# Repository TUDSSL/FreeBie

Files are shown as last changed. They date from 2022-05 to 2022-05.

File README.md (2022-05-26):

# Battery-free Bluetooth That Works
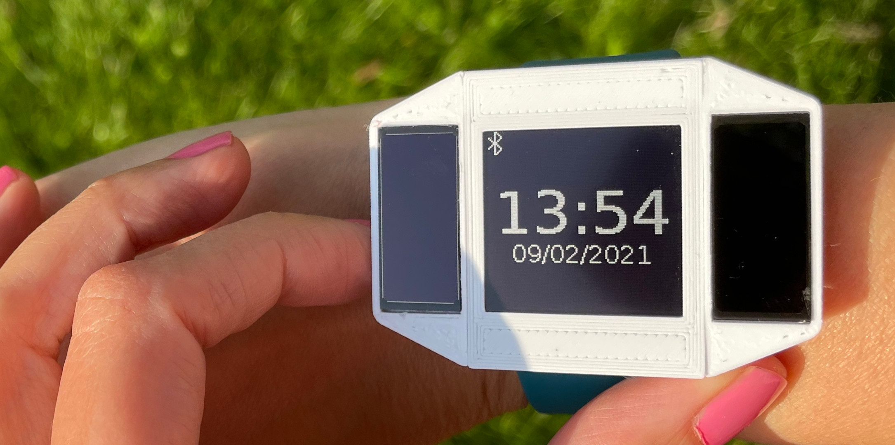
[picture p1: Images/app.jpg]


## Abstract
We present an architecture for intermittently-powered wireless communication systems that does not require any changes to the official protocol specification. Our core idea is to save the intermediate state of the wireless protocol to non-volatile memory within each connection interval. The protocol state is then deterministically restored at a predefined (harvested energy-dependent) time, which follows the connection interval. As a case study for our architecture, we introduce FreeBie: a battery-free intermittently-powered Bluetooth Low Energy (BLE) mote. To the best of our knowledge FreeBie is the first battery-free active wireless system that sustains bi-directional communication on intermittent harvested energy. The strength of our architecture is articulated by FreeBie consuming at least 9.5 times less power during device inactivity periods than a state-of-the-art BLE device.

<!-- ![Intermittency Introduction](https://github.com/TUDSSL/FreeBie/blob/master/Images/intro.svg) -->
<!-- ![System Diagram](https://github.com/TUDSSL/FreeBie/blob/master/Images/diagram.svg) -->

## Artifact
We describe the process to reproduce the results presented in the paper.

### Repository structure
The diagram below describes structure and purpose of the most important directories of the FreeBie project.
* * *
 * Hardware
   * design: KiCad design files
   * schematic: PDF schematic
   * manufacturing: Bill of materials, Gerber files (per version)
 * Software
   * bin: Location of compiled application binaries
   * build: Location of build files
   * ckpt-app: Application process files per application
     * fw-update
     * smartwatch
     * template
   * ckpt-os: OS process files
   * config: CMake and project configuration files
   * libs: Drivers for external system components
   * platforms: Pin definitions
   * third-party
     * Cordio: Network process files
 * Evaluation
   * hosts
     * fw-update: Firmware for the firmware update host
     * smartwatch: Android app for smartwatch host
     * end-device
       * softdevice: Power comparison application
   * Plotting
     * plot.sh: Script generating all the plots in the paper
     * *.py: Figure-specific Python script invoked by plot.sh
 * Measurements
     * raw: Raw measurements
     * converted: Measurements converted to CSV format
     * traces: 24H trace and replay script
* * *

### Evaluation Setup
#### Code Generation and Programming Tools.

To compile FreeBie runtime we used the [GNU Arm Embedded Toolchain (9.3.1)](https://developer.arm.com/tools-and-software/open-source-software/developer-tools/gnu-toolchain/gnu-rm/downloads) and [CMake (3.19.1)](https://cmake.org) to build the project. To program the MCU we used the [J-Link debug probe](https://www.segger.com/products/debug-probes/j-link/models/j-link-edu) with the accompanying J-Link software. We used Linux in order compile and evaluate FreeBie. In this artifact, only Linux instructions are provided, although (untested) Windows or Mac OS could also be used to build the system.

#### Trace Recording Tools.

We used [Saleae Logic Pro 16 logic analyzer](http://downloads.saleae.com/specs/Logic+Pro+16+Product+Fact+Sheet.pdf), to record on-device FreeBie signals. To capture and analyze over-the-air master/end-device BLE packets exchanges we used [Nordic Semiconductors nRF sniffer](https://www.nordicsemi.com/Products/Development-tools/nRF-Sniffer-for-Bluetooth-LE) and [Wireshark](https://www.wireshark.org}) as protocol analyzer.

#### Controlled Test Environment.

We put FreeBie at the bottom of a closed light box. A wirelessly-controlled [LED bulb](https://www.philips-hue.com/en-gb/p/hue-white-ambiance-1-pack-e27/8718699673147) was installed at the top of the box to create repeatable and controlled light source. A [luminosity meter](https://www.uni-trend.com/html/product/Environmental/Environmental_Tester/Mini/UT383.html) was placed next to FreeBie mote to measure the exact luminosity projecting onto FreeBie's solar panels.

#### Power Measurement Process.

Connection event as well as the sleep power consumption for the [Packetcraft BLE network stack](https://github.com/packetcraft-inc/stacks), Nordic Semiconductors BLE SoftDevice and our intermittently-powered BLE stack were measured using a [STMicroelectronics X-NUCLEO-LPM01A power measurement board](https://www.st.com/en/evaluation-tools/x-nucleo-lpm01a.html). FreeBie's power consumption whilst the processor domain is off was measured with [Keithley 2450 SMU](https://download.tek.com/datasheet/1KW-60904-2_2450_Datasheet_072021.pdf). Power consumption during sleep and power off was measured at 1.8V. Power consumption of Packetcraft and SoftDevice is measured on the NRF52840 development kit, FreeBie power measurements are measured on the FreeBie mote. The BLE connection event power consumption for Packetcraft and SoftDevice was measured at a 1.8V, while BLE connection event for FreeBie was measured at 2.67V. We measure the connection event after the device has been running for five minutes, selecting a connection event with an empty PDU. The consumed energy results presented in Figure 12 Consumed Energy are computed as the sum of the energy consumed during the selected connection event and during the idle period (power off for FreeBie and sleep for Packetcraft and SoftDevice.).

#### FreeBie Hardware.

In order to reproduce the results of the paper a FreeBie mote is required. In the *Hardware* folder of the repository, all files to reproduce the mote are provided, such as the design files, Gerber files and the bill of materials.

### Building the FreeBie Software

In order to build the FreeBie software, from the *Software/build* directory the following commands need to be executed.

```bash
$ cmake ..
$ make install
```

As a result of these operations, the project is compiled and the resulting programmable binaries of the applications are moved to the *Software/bin* directory. Next, the compiled binary of the application that is being tested should be flashed to the FreeBie mote.

#### Programming the FreeBie Mote.

In order to assist with programming the FreeBie mote during intermittent operation, a button is placed next to the programming header on the mote. When this button is pressed during startup of the MCU, the MCU remains in a perpetual loop, allowing the device to be programmed. Note that this button only works during the start up of the MCU and during operation the mote might be unable to be flashed as the power to the MCU may be switched off.

## Results Reproduction

### Smartwatch Application

In order to reproduce the results related to the smartwatch application please make sure that the smartwatch binary is programmed to the FreeBie mote first.

#### Building the Android Application.

In order to build the Android application, open the project (located in *evaluation/hosts/smartwatch*) in the Android Studio and then proceed with building the APK. Then a *.apk* file should be available in the *evaluation/hosts/smartwatch/build/outputs/apk* directory of the project. The APK must then be installed on the phone through Android Studio or transferred to the phone and installed manually. When opening the app for the first time, it will ask for permissions that must be granted in order for the app to be able to function. For more information please refer to the [Android Developer website]().

#### Measurement.

First the logic analyzer is connected to the testpoints on the FreeBie mote. These testpoints provide the tracing information about the system state used to generate Figure 11 FreeBie smartwatch operation. For the measurement, the programmed FreeBie mote with the smartwatch binary is placed in the light box. The phone should be placed within range of the FreeBie mote for the devices to be able to connect. Next the variable light should be set to output the amount of light specified in the desired scenario to be replicated.

When the light is switched on the FreeBie mote starts harvesting energy and when enough energy is harvested the FreeBie mote should automatically switch on. The smartphone should then automatically connect to the FreeBie mote and time should appear on the LCD screen.

#### 24 hour experiment.

For the 24 hour experiment the same procedure as before is used, but instead of a static lighting, a script (available in the *Measurements/traces* directory) is used to replay a prerecorded luminosity trace of a person wearing a smartwatch for 24 hours. In order to execute the Python script, first the dependencies have to be installed, assuming Python is already installed. For this the following command needs to be executed.

```bash
$ cd Measurements/traces
$ pip install -r requirements.txt
```

Second the tool communicating with the light has to be installed and configured. Please follow the instructions on the website of the [tool](https://github.com/bahamas10/hue-cli). After the software is able to control the light, the script can be executed, replaying 24H of the prerecorded light trace.

```bash
$ python replay_lux.py -f \
  logger-2021-11-20_09-36-46-549.csv -skips 5
```

### Firmware Update Application

We first note that in order to reproduce the results presented in the smartwatch application please make sure the *fw-update* binary is programmed to the FreeBie mote.

#### Building and Flashing the Host Firmware.

First plug in the development kit and make sure that is is powered and detected. Then from the main project directory execute the following command.

```bash
$ cd Evaluation/hosts/          \
     fw-update/  \
     nRF5_SDK_17.0.2/           \
     examples/ble_central/      \
     ble_app_custom_c/          \
     pca10056/s140/armgcc
$ make
$ make flash_softdevice
$ make flash
```

The development kit should now be flashed with the correct firmware. Turn the development kit off and on. Now it is ready to start the firmware update as soon as the FreeBie mote is detected.

#### Measurement.

In order to generate the Evaluation of firmware update plot in FreeBie Evaluation section, the logic analyzer is connected to the test points on the FreeBie mote. These test points provide the tracing information about the system state used to generate Figure 13 Evaluation of firmware update. For the measurement, the programmed FreeBie mote with the *fw-update* binary is placed in the light box. The development kit, acting as firmware update host, should be placed within range of the FreeBie mote for the devices to be able to connect. For the firmware update application we did not connect the display to the FreeBie mote.

When the light is switched on the FreeBie mote starts harvesting energy and when enough energy is harvested the FreeBie mote should automatically switch on. The firmware update host should connect to the FreeBie mote and the firmware update should start automatically.

### Reference Comparison

In order to produce figures 8, 9 and 12 we used a minimal working example (named *template*) of our software that only actively uses the network process and the OS process. In this application after the BLE connection is established and the database discovery has been completed, only empty packets are sent. Hence, this forms a point of reference for other experiments.

#### Template Configuration.

From within the *CMakefile* file of *template*, checkpointing can be switched off by commenting the following lines:
```CMake
set(CHECKPOINTING 1)
set(CHECKPOINTING_TIMING 1)
```
Without checkpointing enabled this example serves as the Packetcraft comparison point and is representative of traditional operation; with checkpointing enabled---as FreeBie. When the checkpointing is active, a connection update request to the selected parameters is sent after connecting. To force the same behavior for the non-checkpointing version, the line *set(COMPARE_NO_CHECKPOINT 1)* needs to be uncommented. When modifying the CMakefiles, the code has to be recompiled with the same steps as described in Section Building the FreeBie Software.

#### Intermittent versus Non-intermittent.

In order to reproduce the results in Figure 8 the FreeBie mote is again placed in a light box at the specified light level and the information about the system state are recorded by the logic analyzer. The experiment is ran for both checkpointing enabled and checkpointing disabled. The non-checkpointed version runs out of energy and not be able to recover the connection as the system state is lost.

#### Connection Recovery.

For the results in Figure 9, the FreeBie mote is not powered by the solar panels but through an external power supply connected to the test point *VSol* on the back of the FreeBie mote. In this case *template* with connection recovery enabled (*set(RECOVER_CONNECTIONS 1)*) and checkpointing enabled is used. After a connection to the FreeBie mote has been established, the power to the device is disabled until the device suffers from a power failure. Then power is resumed and the device attempts recovery.

#### Power Measurement.

For the results in Figure 12 *template* is used with checkpointing disabled, serving as the Packetcraft comparison point; with checkpointing enabled---as FreeBie. As the comparison point of SoftDevice the code provided in *Evaluation/end-device/softdevice* is used. From the main project directory the code can be compiled and flashed using the following commands.

```bash
$ cd Evaluation/end-device/softdevice/ \
     examples/ble_peripheral/ \
     ble_app_pwr_profiling/ \
     pca10056/s140/armgcc
$ make
$ make flash_softdevice
$ make flash
```

Please refer to the Evaluation Setup Section for more information about the power measurement process.

### Plotting

By executing the *plot.sh* script in the *Plotting* directory all of the plots can be generated. Please note that due to the size of the 24 hour plot this might take more than 15 minutes and requires a system with at least 16GB of RAM. All plotting scripts use Python and assume Python is installed on the system; all Python dependencies can be installed via the *requirements.txt* file using the following commands.

Since the measurements files are large they are only included in the version of the artifact hosted on [Zenodo](https://doi.org/10.5281/zenodo.6583725)

```bash
$ cd Plotting
$ pip install -r requirements.txt
$ plot.sh
```

## License
The Project adopts the MIT license unless noted otherwise, As Packetcraft licenses its software stack under the Apache 2.0 license our code in the folder Software also adopts this license unless noted otherwise.

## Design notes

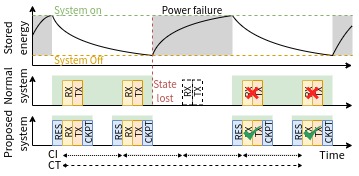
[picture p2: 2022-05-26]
Images/intro.jpg

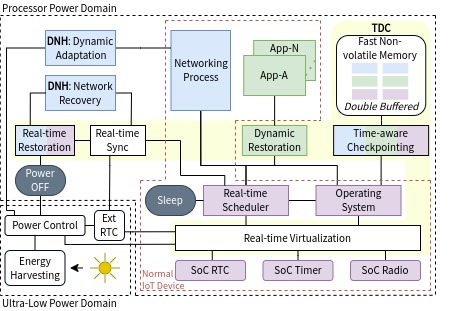
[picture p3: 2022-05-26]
Images/diagram.jpg

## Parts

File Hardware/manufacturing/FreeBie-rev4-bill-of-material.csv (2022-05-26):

Item | Qty | Reference(s) | MPN
1 | 11 | C1, C3, C4, C7, C8, C9, C10, C21, C22, C23, C25 | GRM155R71C104KA88J
2 | 2 | C5, C6 | 0402ZD105KAT2A
3 | 1 | C11 | GJM1555C1H470FB01D
4 | 2 | C12, C16 | LMK105BBJ475MVLF
5 | 2 | C13, C15 | GCM155R71H103KA55D
6 | 2 | C14, C17 | -
7 | 2 | C18, C19 | CPX3225A
8 | 1 | C20 | GRM188R60J226MEA0D
9 | 1 | J1 | 52745-1097
10 | 1 | J2 | -
11 | 2 | J3, J4 | 202396-0207
12 | 6 | JP1, JP2, JP9, JP11, JP12, JP14 | -
13 | 1 | JP3 | -
14 | 1 | L1 | VLS252012CX-220M-1
15 | 1 | L2 | VLS252012CX-100M-1
16 | 10 | R1, R3, R5, R6, R7, R8, R9, R15, R21, R22 | RC0402FR-0710ML
17 | 2 | R2, R10 | RC0402FR-07100KL
18 | 1 | R4 | RC0402FR-0710ML
19 | 1 | R12 | MCHVR02FTFY3904
20 | 2 | R13, R16 | CRCW04029M10FKED
21 | 1 | R14 | CRCW04025M23FKED
22 | 1 | R17 | CRCW04023M16FKED
23 | 1 | R18 | RMCF0402FT4M53
24 | 1 | R19 | MCHVR02FTFY6804
25 | 1 | R20 | RC0402FR-07200KL
26 | 1 | SW2 | B3U-1000P
27 | 13 | TP1, TP2, TP3, TP4, TP5, TP6, TP7, TP9, TP11, TP12, TP13, TP14, TP18 | SMOX/060/B1/HT
28 | 1 | U1 | BQ25570RGR
29 | 1 | U2 | 74AUP1G74
30 | 1 | U3 | 74AUP1G97DCK
31 | 1 | U4 | OPT3004DNPR
32 | 1 | U5 | BMA400
33 | 1 | U6 | TS3A4741DCN
34 | 1 | U7 | EYSKBNZWB
35 | 1 | U8 | MB85RS4MT
36 | 1 | U9 | SN74AUP3G34RSE
37 | 1 | U10 | AM1815
38 | 1 | U11 | SN74AUP1G04DCK
39 | 1 | U12 | SN74AUP1G34DCK
40 | 1 | Y1 | ABS07W-32.768KHZ-J-1-T
Misc:
 | 2 | Solar panel | EX2-1V50
 | 1 | Screen | LS013B7DH03
 | 10 | Solar panel connector contact | 5013340000
 | 2 | Solar panel connector connector | 5013300200

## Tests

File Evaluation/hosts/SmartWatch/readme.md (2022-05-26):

Bluetooth handling is based on:https://github.com/weliem/blessed-android

Also inspired by https://github.com/androidthings/sample-bluetooth-le-gattserver

With mail handling from https://stackoverflow.com/a/28689722

Time profile taken from https://github.com/androidthings/sample-bluetooth-le-gattserver

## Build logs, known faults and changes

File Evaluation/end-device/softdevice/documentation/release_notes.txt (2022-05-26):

nRF5 SDK v17.0.0
------------------------
Release Date: June, 2020

Highlights:

- Added support for a new chip: nRF52820
- Added support for a new SoftDevice: S122 
 (size-optimized central-only Bluetooth Low Energy SoftDevice)
- Added a driver for the new RF front-end module nRF21540
- Removed IoT components and examples
- Removed Keil 4 support

The following toolchains/devices have been used for testing and verification:

 - ARM: MDK-ARM version 5.25
 - GCC: GCC ARM Embedded 9.2019q4.major
 - IAR: IAR Workbench 7.80.4
 - SES: SES 4.50

*****
Note for IAR 8 users:
(Libraries for IAR 8 require wchar_t to be of size 32 bits while IAR 7 requires 16 bits).

To run a project using IAR 8, follow these intructions:
 - Open the IAR project in IAR 8. The IAR workbench will automatically generate an IAR 8 compatible project file.
 - If the project contains one of the precompiled libraries listed below, replace it
   with the IAR 8 compatible alternative (there are no projects targeting nRF51 in this SDK).
 - Save the project.
 - When building the project, you might get the warning: "The header file 'cmsis_iar.h' is obsolete and should not be used. [...]".
    - The problem is described in DevZone post: https://devzone.nordicsemi.com/f/nordic-q-a/31123/iar-ewarm-8-22-1-complains-about-cmsis_iar-h
      The solution is to remove all occurrences of #include <cmsis_iar.h>.

The affected libraries are:
 - micro-ecc crypto:
    - IAR7: Includes library located in the folder named “…_iar\…”.
    - IAR8: Switch to using the library from the folder named “…_armgcc\…”.
 - nrf_cc310, nrf_cc310_bl, and nrf_oberon:
    - IAR7: Link to a library where “short_wchar” is part of the folder name.
    - IAR8: Link to a library without “short_wchar” in part of the folder name.
 - Gazell, NFC Tag, and 802.15.4:
    - IAR7: Includes the library where the file name ends with “_iar”.
    - IAR8: Switch to using the library with similar file name that ends with “_gcc”.
*****

Supported SoftDevices:
 - S112 v7.x.x
 - S113 v7.x.x
 - S122 v8.x.x
 - S132 v7.x.x
 - S140 v7.x.x
 - S212 v6.1.x
 - S312 v6.1.x
 - S332 v6.1.x
 - S340 v6.1.x

Supported boards:

- PCA10040
- PCA10040E (nRF52810 emulation on PCA10040)
- PCA10056
- PCA10056E (nRF52811 emulation on PCA10056)
- PCA10100 (support in selected examples)
- PCA10100E (nRF52820 emulation on PCA10100)
- PCA10059 (support in selected examples)
- D52DK1 from Garmin Canada (only for ANT examples)
- PCA10112 (nRF52840 with the nRF2140 front-end chip)

For other devices and boards, see the SDK documentation, section "Using
the SDK with other boards".

*** New features
*****************

** Drivers and libraries **

- nRF21540 Front-End Module support:
    - New driver supporting the nRF21540 RF front-end module
      can be found in '.\driver_ext\nrf21540\'
    - The DTM and Radio Test examples have been updated
      to include the nRF21540 driver (only GPIO control has been tested).
    - Workaround handling Errata 1 for nRF21540 is not included as part of
      the driver and must be applied separately.
- Radio Test example:
    - Extended the 'start_tx_modulated_carrier' command with an additional
      option for setting the specific number of packets to transmit.
    - Added printing of the received packet statistics in the 'print_rx' command handler.
- nrfx:
    - Updated version to 1.8.4.
    - Added support of the nRF52820 device.
    - Added new SAADC driver backported from nrfx 2.2.0 branch.
- nrf_cc310:
    - Updated version to 0.9.13.
    - Bugfix release with new mechanism for enabling and disabling the hardware
      and for interrupt masking. See Migration Guide for details.
- nrf_cc310_bl
    - Updated version to 0.9.13.
    - Bugfix release with new mechanism for interrupt masking.
- nrf_oberon
    - Updated version to 3.0.5.
    - General version update supporting more nRF5 architectures.
    - Addition of header files for the mbedcrypto frontend.
	  See Migration Guide for details.
- USB: added support for nRF52820.

*** Changes
***********

** Drivers and libraries **

- Radio Test example: refactored to use the Radio HAL module (nrf_radio.h) functions.
- nrfx: see the nrfx 1.8.4 changelog in modules/nrfx/CHANGELOG.md.

** Crypto **

- nrf_cc310 library now automates enabling and disabling of CryptoCell hardware
  and interrupts. It is no longer done in nrf_crypto. See Migration Guide for details.

** NFC **

- T4T: allowed dynamic R/W NDEF message buffer changing.
  Now you can change the NDEF buffer in any protocol state,
  without having to disable the T4T emulation.
- T4T: added pointer to the NDEF message buffer for the 'NDEF Updated' event.

** Bluetooth Low Energy **

- Scanning Module: removed the 'Scan Request' event
  that is irrelevant for the scanner role.
- External Tile library: integrated a new library version.

** DTM **

 - Updated DTM to support the nRF52820 device.
 - Added new example targets:
   - pca10100e: for nRF52820 emulation on pca10100.
   - pca10112: a version for a development kit with the nRF52840 device
     and the nRF2140 front-end chip.

*** Bug fixes
****************

** Drivers and libraries **

- nrfx: see the nrfx 1.8.4 changelog in modules/nrfx/CHANGELOG.md.
- Fixed a bug where FDS garbage collection ran on more pages than necessary,
  causing unnecessary flash wear.

** ANT **

- ANT Shared Channels example (slave project): fixed array size check.

** NFC **

- T4T: fixed detecting of the end of reading NDEF message procedure
 (NFC_T4T_EVENT_NDEF_READ).
- T4T: fixed an issue where NDEF Read event was triggered even when
  NDEF Message was empty.

** Bluetooth Low Energy **

- Fixed nrf_sd_def.h file contents in all SoftDevices
  (in some cases, the definitions in this file were outdated).
- External Tile library: fixed a few minor issues.
- Nordic UART Service: added a null-pointer check in the
  notification transmitted handler.
- Fixed a vulnerability issue reported by IOActive where malformed
  advertising data could be used to attack a device that does scanning.
  The fix is included in ble_advdata_search() in ble_advdata.c where
  an extra check has been added to ensure that the length values specified
  within the advertising packet are within the boundary of the advertising packet.

** DFU **

- SES will now return a linker error if the bootloader is too large.
- Fixed a bug that caused SD+BL updates to fail if the SD had signature boot validation.
- Fixed an error in the code that booted the app, which could happen
  with certain optimization settings.
- Fixed a false positive assert that could sometimes happen after a reset
  during an upgrade.
- Fixed a bug that caused compilation errors when building with a board with no buttons.

** DTM **

- DTM reports regarding Max Octets are now correct for devices without long range support.

** USB **

- Fixed issues and optimized app_usbd_string_desc.
- Fixed issues in USB CLI backend when handling a port close.

** Proprietary **

- Gazell: fixed an assertion that would be sometimes generated after
  a packet transmission.
- ESB: fixed a bug in the nrf_esb_pop_tx function where packages would get sent anyway
  in certain situations.

*** Known Issues
****************

** General **

- The workaround for Anomaly 198 for nRF52840 SPIM3 peripheral
  that has been implemented in nrfx_spim cannot be used with a SoftDevice.
  Flag NRFX_SPIM3_NRF52840_ANOMALY_198_WORKAROUND_ENABLED must be set to zero.
  The workaround based on a dedicated RAM block for SPIM3 must be used instead.
- usbd_msc example has a limitation.
  With setting "APP_USBD_CONFIG_EVENT_QUEUE_ENABLE = 0",
  when USB cable is unplugged and re-plugged, the application goes into an endless loop.
  This is due to an issue in the unsupported block device library.

** Bluetooth Low Energy **

- GATTC: the ble_gattc_service_t::uuid field is incorrectly populated
  in the BLE_GATTC_EVT_PRIM_SRVC_DISC_RSP event if the
  sd_ble_gattc_primary_services_discover() or sd_ble_gattc_read()
  are called when a Primary Service Discovery by Service UUID is already ongoing.
  When the application has called sd_ble_gattc_primary_services_discover(),
  it should wait for the BLE_GATTC_EVT_PRIM_SRVC_DISC_RSP event before calling
  sd_ble_gattc_primary_services_discover() or sd_ble_gattc_read().
- BLE Interactive CLI example: the command to set a custom ATT MTU only takes
  effect on the subsequent connection and the updated MTU parameter is not
  maintained in further connections with the same peer, even when bonded.
- ANT Shared Channels example: when testing a Bluetooth Low Energy connection
  with an Android device, the link is terminated by Android due to unhandled LL requests.
- Bluetooth ANCS example: when connected from iPhone and pressing DK buttons,
  the example may assert before the Bluetooth Low Energy link is authenticated.

** Crypto **

- The nrf_crypto CLI example may fail when using an ECC private key converted
  from raw function for specific curve types.

** Drivers and libraries **

- The SAADC driver (from nrfx 1.8.x) does not handle detection limits 'high' and 'low'
  correctly if SAADC resolution is greater than 10 bits.
  SAADC driver ported from nrfx 2.2.x is not affected by this.
- USBD:
  - The library may handle Remote Wakeup incorrectly.
  - Issuing a SET_ADDRESS(0) request does not cause the device to change
    its state to default.
  - The device does not STALL when a DATA transaction is received outside of SETUP.
    It ACKs instead.
- The following macros defined in boards.h work only with pins on port 0:
  - LEDS_OFF
  - LEDS_ON
  - LED_IS_ON
  - LEDS_INVERT
  - LEDS_CONFIGURE
- The low_power_pwm library does not correctly initialize GPIOs
  that are placed on PORT1 in the low_power_pwm_init function.
  This indirectly affects the led_softblink library and can also affect
  the DFU open bootloader.

==============================

nRF5 SDK v16.0.0
------------------------
Release Date: October, 2019

Highlights:

- Added support for a new chip: nRF52833
- Added support for new BLE SoftDevices version 7, as well as the new SoftDevice S113.
- Added an external Tile BLE library and a corresponding example
  demonstrating the "find me" feature.
- App Timer v2 is now out of experimental and replaces the legacy App Timer
  in all examples.

The following toolchains/devices have been used for testing and verification:

 - ARM: MDK-ARM version 5.25
 - GCC: GCC ARM Embedded 7.2018q2.update
 - IAR: IAR Workbench 7.80.4
 - SES: SES 4.18

*****
Note for IAR 8 users:
(Libraries for IAR 8 require wchar_t to be of size 32 bits while IAR 7 requires 16 bits).

To run a project using IAR 8, follow these intructions:
 - Open the IAR project in IAR 8. The IAR workbench will automatically generate an IAR 8 compatible project file.
 - If the project contains one of the precompiled libraries listed below, replace it
   with the IAR 8 compatible alternative (there are no projects targeting nRF51 in this SDK).
 - Save the project.
 - When building the project, you might get the warning: "The header file 'cmsis_iar.h' is obsolete and should not be used. [...]".
    - The problem is described in DevZone post: https://devzone.nordicsemi.com/f/nordic-q-a/31123/iar-ewarm-8-22-1-complains-about-cmsis_iar-h
      The solution is to remove all occurrences of #include <cmsis_iar.h>.

The affected libraries are:
 - micro-ecc crypto:
    - IAR7: Includes library located in the folder named “…_iar\…”.
    - IAR8: Switch to using the library from the folder named “…_armgcc\…”.
 - nrf_cc310, nrf_cc310_bl, and nrf_oberon:
    - IAR7: Link to a library where “short_wchar” is part of the folder name.
    - IAR8: Link to a library without “short_wchar” in part of the folder name.
 - Gazell, NFC Tag, and 802.15.4:
    - IAR7: Includes the library where the file name ends with “_iar”.
    - IAR8: Switch to using the library with similar file name that ends with “_gcc”.
*****

Supported SoftDevices:
 - S112 v7.x.x
 - S113 v7.x.x
 - S132 v7.x.x
 - S140 v7.x.x
 - S212 v6.1.x
 - S312 v6.1.x
 - S332 v6.1.x
 - S340 v6.1.x

Supported boards:

- PCA10040
- PCA10040E (nRF52810 emulation on PCA10040)
- PCA10056
- PCA10056E (nRF52811 emulation on PCA10056)
- PCA10100 (support in selected examples)
- PCA10059 (support in selected examples)
- D52DK1 from Garmin Canada (only for ANT examples)

For other devices and boards, see the SDK documentation, section "Using
the SDK with other boards".

*** New features
*****************

** Drivers and libraries **

- nRF52833: added USB support - both USB device hardware driver and USB Device library.
- Radio Test Example: added a project for nRF52833.

** BLE**

- Added a new library GATT Queue which can be used for buffering GATT procedures when
  the SoftDevice cannot process them immediately. It can be used with, for example,
  Indications, Read or Write Requests etc. The queued procedure is automatically
  retried when events from the SoftDevice indicate that it can be processed.
  Most of the GATT Client libraries use this module.
- Added support for the new SoftDevice S113 in selected BLE examples.
- Improved Database Discovery Module design to enable multiple instances,
  for example to perform independent discovery on each connection.
- BLE Interactive CLI Example: added discovery of 128-bit UUID Services and
  Characteristics at the first attempt.
- Advertising Module: improved dynamic advertising data update, no additional buffer
  is needed now - swap buffer was introduced within the module implementation.
- Added a new external BLE library: Tile, and a corresponding example: ble_app_tile.
  The project implements proprietary GATT services for demonstrating the
  "find me" feature.
  The integrated modules include source code as well as a precompiled linkable library.

** DFU **

- Updated documentation with information on Secure Boot and platform architecture
  security.

** NFC **

- Added support for new chip: nRF52833. Added corresponding projects in selected
  examples.

** USB **

- APP_USBD_BCD_VER_MAKE macro now includes a sub-minor version parameter.
- Feature reports functionality is now supported in HID generic class.

** Proprietary **

- ESB: added support for the new chip nRF52833.
- Gazell: added support for nRF52810 and nRF52811.

** DTM **

- Updated Direct Test Mode to support nRF52833.

*** Changes
***********

** Drivers and libraries **

- app_timer: App Timer v2 moved out of experimental. It is updated and
  API-compatible with the old implementation making it easy to replace.
  All SDK examples using App Timer are updated to use the new version.
- libuarte:
   - libuarte moved out of experimental.
   - nrf_libuarte renamed to nrf_libuarte_drv (file names and API).
   - Added option to use an app_timer instance for RX timeout instead of the TIMER or
     RTC peripheral.
- nrf_cli: CLI now automatically adds an `\r` character before each printed `\n`
  character. This feature can be switched off in sdk_config with flag
  `NRF_FPRINTF_FLAG_AUTOMATIC_CR_ON_LF`.
- FDS: FDS-specific error codes have been moved so their values do not overlap with
  other error codes.
  Also, NRF_SUCCESS is now used instead of FDS_SUCCESS.

** Crypto **

- Updated OPTIGA Trust X library code and example.
- Updated the nrf_oberon library version to 3.0.1, changing the API prefixes from
  occ_* to ocrypto_*.

** BLE **

- Peer Manager:
    - Changed the pm_peer_data_* API to use uint32_t length variables instead of
      uint16_t.
    - The flash cleaning algorithm in peer_manager_handler now also runs garbage
      collection if other users of FDS have deleted data.
    - The fds_error member variable has been removed from PM events.
    - Added a LESC flag to pm_conn_sec_status_t.
    - Add a new function pm_sec_is_sufficient() where the security state of the
	  connection is checked against a reference security state.
    - Function pm_sec_is_sufficient() is now used internally when responding
   	  to slave security requests.
    - pm_handler has been augmented with new event handlers based on
      pm_sec_is_sufficient().
- Advertising Module: removed obsolete API.
- ble_conn_state: Added a LESC flag to connection state (i.e. whether LESC was used
  for bonding/pairing). It can be false even if LESC was used.
  See Peer Manager for a completely accurate reporting of LESC.
- BLE Central UART Example: added support for Windows-type line end characters.
- Running Speed and Cadence Example: added handling of the Database Discovery Available
  event.
- Heart Rate Example:
    - Changed default configuration for nRF52810 and nRF52811.
         - Service Change Characteristic disabled.
         - Disabled protection against repeated pairing attempts in Peer Manager.
         - FDS: Reduced number of virtual flash pages to use.

** DFU **

- Bootloader start address is now placed in UICR at compile time, and the MBR page is
  populated at runtime. This is to mitigate problems with flashing
  where the MBR was erased.
- The MBR folders have been merged into a single folder since the MBR is identical for
  all nRF52 variants.
- The bootloader now disallows upgrading the SoftDevice to another family
  (e.g. s140 -> s113).
- nrf_bootloader_app_start() can no longer be called from an interrupt handler.
- BLE DFU: Disconnect link when aborting DFU (OP_ABORT).
- The bootloader will now wait a configurable number of milliseconds before each chip
  reset. Configured with NRF_BL_RESET_DELAY_MS.
- Added a configuration option for disabling a debug port: NRF_BL_DEBUG_PORT_DISABLE.
- When the bootloader is compiled in a configuration where the app does not need access
  to the settings page, the page itself, not just the backup, is locked before booting
  the app.

** USB **

- USB driver: all changes listed here:
  https://github.com/NordicSemiconductor/nrfx/blob/v1.8.0/CHANGELOG.md
- USB libraries: APP_USBD_AUDIO_AC_IFACE_SUBTYPE_OUTPUT_TERNINAL
  has been renamed to APP_USBD_AUDIO_AC_IFACE_SUBTYPE_OUTPUT_TERMINAL.
- bDescriptorSubType field in app_usbd_audio_ac_iface_header_desc_t struct
  has been renamed to bDescriptorSubtype.
- bmRequest field in app_usbd_cdc_notify_t struct has been renamed to bRequest.
- bmRequest field in app_usbd_setup_t struct has been renamed to bRequest.
- New values have been added to app_usbd_msc_subclass_t and app_usbd_msc_req_t enums.
- Terminal link in AS Interface Descriptor has been added as a parameter
  for the APP_USBD_AUDIO_GLOBAL_DEF macro.

*** Bug fixes
****************

** Drivers and libraries **

- FDS: fixed two bugs where a power loss at very specific times during garbage
  collection could corrupt the file system, making FDS unable to initialize and return
  FDS_ERR_NO_PAGES on initialization.
- FDS: fixed a bug that prevented using the last word of a flash page to save a record.

** ANT **

- Fixed a bug in ANT-FS Library, where incoming burst frames could be incorrectly
  handled due to wrong bitfield checking.

** NFC **

- Fixed a bug where the Tag could respond to an ALL_REQ frame with incorrect timing when
  in the sleep state.
  This bug would occur after the Tag received an SLP_REQ frame and when an ALL_REQ frame
  was received shortly after - in a time shorter than what was configured
  in the NFCT FRAMEDELAYMAX register (in Type 4 Tag default configuration: 4.8 ms).

** BLE **

- Eddystone: fixed bug for handling 0.625 unit in advertising interval.
- Advertising Module: fixed a bug where a secondary PHY configuration might get
  overwritten.
- Advertising Data Encoder: fixed a bug causing underflow of a return value
  of the parsing function when malformed data was provided as input.
- Nordic UART Service: fixed a bug where incorrect Characteristic CCCD
  was checked on connection event.
- Database Discovery: fixed counting of discovered services.
   - Fixed a bug where "available" events (indicating the module is ready
     for the next discovery process) were not triggered.
- BLE Interactive CLI Example: fixed a bug where not all
  GATT Characteristics and Descriptors were discovered when a short ATT MTU was used.
- Peer Manager:
    - Fixed a bug where peer ranks would not work after deleting all peers.
    - Fixed a bug where the indications for service changed would be dropped
      if they were sent at the same time as an MTU exchange.

** DFU **

- Fixed a bug where resuming a DFU procedure with a disconnect (but no reset)
  in-between could leave the bootloader in a semi-locked state.
- Fixed an issue where write protection of the application was not applied.

*** Known Issues
****************

** General **

- The workaround for Anomaly 198 for nRF52840 SPIM3 peripheral
  that has been implemented in nrfx_spim cannot be used with a SoftDevice.
  Flag NRFX_SPIM3_NRF52840_ANOMALY_198_WORKAROUND_ENABLED must be set to zero.
  The workaround based on a dedicated RAM block for SPIM3 must be used instead.

** BLE **

- GATTC: the ble_gattc_service_t::uuid field is incorrectly populated
  in the BLE_GATTC_EVT_PRIM_SRVC_DISC_RSP event if the
  sd_ble_gattc_primary_services_discover() or sd_ble_gattc_read()
  are called when a Primary Service Discovery by Service UUID is already ongoing.
  When the application has called sd_ble_gattc_primary_services_discover(),
  it should wait for the BLE_GATTC_EVT_PRIM_SRVC_DISC_RSP event before calling
  sd_ble_gattc_primary_services_discover() or sd_ble_gattc_read().
- The TFTP Background DFU example has known instabilities.
- The Tile example disconnects when notifications in the Tile service are on
  and the application sends the first Battery Level notification.
- BLE Interactive CLI example: the command to set a custom ATT MTU only takes
  effect on the subsequent connection and the updated MTU parameter is not
  maintained in further connections with the same peer, even when bonded.
- ANT Shared Channels example: when testing BLE connection with an Android device,
  the link is terminated by Android due to unhandled LL requests.
- Bluetooth ANCS example: when connected from iPhone and pressing DK buttons,
  the example may assert before the BLE link is authenticated.

** Crypto **

- The nrf_crypto CLI example may fail when using ecc private key converted
  from raw function for specific curve types.

** Drivers and libraries **

- The SAADC driver does not handle detection limits 'high' and 'low' correctly
  if SAADC resolution is greater than 10 bits.
- USBD:
  - The library may handle Remote Wakeup incorrectly.
  - Issuing a SET_ADDRESS(0) request does not cause the device to change
    its state to default.
  - The device does not STALL when a DATA transaction is received outside of SETUP.
    It ACKs instead.

** IoT **

- The MQTT example does not compile when run on PCA10040 with commissioning
  enabled (COMMISSIONING_ENABLED=1).
- DTLS example: the server and the client application of the DTLS example should
  not be run on two kits. Instead, either the server or the client application
  should be run against the PC application as described in the documentation.

===========================================

nRF5 SDK v15.3.0
------------------------
Release Date: Week 7, 2019

Highlights:

- Added support for a new chip - nRF52811.
- Added support for two new ANT SoftDevices: S312 targeting nRF52810 and nRF52832, and S340 targeting nRF52840.
- Added back support for the ANT SoftDevice S332 v6.1.1, as well as updated the latest SoftDevices S112, S132, S140 and S212 v6.1.1.
- Updated the SDFU solution with ANT transport layer.
- Updated DTM to support nRF52811, and updated the existing code to correctly handle Anomaly 172.

The following toolchains/devices have been used for testing and verification:

 - ARM: MDK-ARM version 5.25
 - GCC: GCC ARM Embedded 7.2018q2.update
 - IAR: IAR Workbench 7.80.4
 - SES: SES 4.12

Note: The selected GCC version has shown instabilities when using the Link Time Optimization feature, and using the feature is not recommended.

*****
Note for IAR 8 users:
(Libraries for IAR 8 require wchar_t to be of size 32 bits while IAR 7 requires 16 bits).

To run a project using IAR 8, follow these intructions:
 - Open the IAR project in IAR 8. The IAR workbench will automatically generate an IAR 8 compatible project file.
 - If the project contains one of the precompiled libraries listed below, replace it with the IAR 8 compatible alternative
   (there are no projects targeting nRF51 in this SDK).
 - Save the project.
 - When building the project, you might get the warning: "The header file 'cmsis_iar.h' is obsolete and should not be used. [...]".
    - The problem is described in DevZone post: https://devzone.nordicsemi.com/f/nordic-q-a/31123/iar-ewarm-8-22-1-complains-about-cmsis_iar-h
      The solution is to remove all occurrences of #include <cmsis_iar.h>.

The affected libraries are:
 - micro-ecc crypto:
    - IAR7: Includes library located in the folder named “…_iar\…”.
    - IAR8: Switch to using the library from the folder named “…_armgcc\…”.
 - nrf_cc310, nrf_cc310_bl, and nrf_oberon:
    - IAR7: Link to a library where “short_wchar” is part of the folder name.
    - IAR8: Link to a library without “short_wchar” in part of the folder name.
 - Gazell, NFC Tag, and 802.15.4:
    - IAR7: Includes the library where the file name ends with “_iar”.
    - IAR8: Switch to using the library with similar file name that ends with “_gcc”.
*****

Supported SoftDevices:
 - S112 v6.1.x
 - S132 v6.1.x
 - S140 v6.1.x
 - S212 v6.1.x
 - S312 v6.1.x
 - S332 v6.1.x
 - S340 v6.1.x

Supported boards:
 - PCA10040
 - PCA10040E (nRF52810 emulation on PCA10040)
 - PCA10056
 - PCA10056E (nRF52811 emulation on PCA10056)
 - PCA10059 (support in selected examples)
 - D52DK1 from Garmin Canada (only for ANT examples)

For other devices and boards, see the SDK documentation, section "Using
the SDK with other boards".

*** New features
*****************

** ANT **

- Added the new ANT Secure DFU Bootloader example.
  The example demonstrates how to use the new ANT transport with Secure DFU components
  (with support only for SES and GCC toolchains).
- Removed legacy ANT bootloader solution.

** Drivers and libraries **

- nrf_cli can now prompt and autocomplete both sorted and unsorted subcommands.
- nrf_libuarte and nrf_libuarte_async now support multiple instances.

** BLE**

- nrf_ble_lesc (part of the Peer Manager) now supports the LESC OOB pairing mode.
  The ble_nfc_pairing_reference_c example demonstrates how to pass the OOB data to the module.

** DFU **

- Added the option to perform signature validation of the application on each boot.
  This functionality requires nrfutil version 5.0.0 or higher.
- The DFU procedure can now mandate strictly increasing application versions.
- Added the option to send applications that will not be activated, but will remain in slot 1 ("external applications").
  This functionality requires nrfutil version 5.0.0 or higher.
- Added masking of GPREGRET and GPREGRET2 registers, enabling the upper 3 bytes of each register to be used by the application independently of the bootloader.

** Crypto **

- Added nrf_crypto backend support for Infineon OPTIGA™ Trust X devices (selected features).
- Added new example to showcase Infineon OPTIGA Trust X functionality: examples/crypto/ifx_optiga_custom_example.

*** Changes
************

** DFU **

- Turned off Link Time Optimization in all DFU projects due to instabilities in the supported GCC compiler.

** Drivers and libraries **

- nrf_cli: CLI will now automatically add the `\r` character before each printed `\n` character.
  This feature can be switched off in sdk_config using flag `NRF_FPRINTF_FLAG_AUTOMATIC_CR_ON_LF`.
- USB: A complete list of changes is available under this link: https://github.com/NordicSemiconductor/nrfx/blob/a0dcb1350f6798f12479921a0a376d00e2316fd4/CHANGELOG.md

** NFC **

- The NFC libraries (nfc_t2t_lib and nfc_t4t_lib) now use the NFCT driver instead of the NFC HAL modules (hal_nfc_t2t and hal_nfc_t4t).
  The NFCT driver is a part of nrfx repository.
- Replaced hal_nfc_t2t and hal_nfc_t4t components with the nrfx_nfct driver.
- Added the NFC platform module (nfc_platform) to abstract runtime environment specific implementation from the driver.
  HFCLK activation, required for NFC to operate correctly, is managed in this module.
- Removed the nfc_fixes.h file with NFC workaround description. The content of this file was moved to nrfx_nfct.h.

** Crypto **

- nrf_oberon, nrf_cc310, and nrf_cc310_bl libraries have changed naming and placement compared to the previous release.
  They are now available in the following folder scheme:
  - GCC and IAR 8.x: lib/<arch>/hard-float/<lib_name>.a
  - IAR 7.80.x: lib/<arch>/hard-float/short-wchar/<lib_name>.a
  - Keil: lib/<arch>/hard-float/short-wchar/<lib_name>.lib
  Due to this naming convention change, updated nrf_cc310 and nrf_cc310_bl library version to 0.9.12.
  Due to this naming convention change, updated nrf_oberon library version to 2.0.7.
- Changed ECC Public Key Validation from "Full" to "Partial" in nrf_crypto backend for ARM CC310.
  This improves LESC pairing and ECDSA verify timing.

*** Bug fixes
****************

** Drivers and libraries **

- nrf_cli: The module can now be used with terminals with no standard background color (for example, white).
- USB: Fixed a bug where USB IRQ was not cleared after unplugging the USB cable.
- Fixed an issue where NRF_LOG_INIT(timestamp, frequency) failed to compile if the logger was disabled.
- Fixed a compilation failure issue when using NRF_LOG_HEXDUMP_WARNING.
- Fixed a scenario where the emulated project delay function (nrfx_coredep_delay_us) did not work correctly.

** BLE **

- Peer Manager:
   - Slave Security Requests received during a pairing or encryption procedure will now be ignored (to align with the BLE specification).
   - Fixed a bug where Peer Manager would misinterpret a peer central's ability to resolve resolvable addresses in directed advertisements.
   - Fixed a bug where Peer Manager would sometimes give a fatal error if the link disconnected during a pairing procedure.
   - Fixed a bug where flash could be full but no Peer Manager event was sent.
   - Fixed a bug where Peer Manager would silently drop Service Changed indications if an ATT MTU exchange was happening at the same time.
- Eddystone:
   - Fixed a bug where EID was not correctly updated.
   - Fixed bug where factory reset would not work correctly when followed by an immediate disconnect.

** DFU **

- Various security improvements and fixes.
- Fixed various bugs in background DFU.
- Fixed bugs that appeared when combining transports (for example, UART + BLE).

** DTM **

- Fixed a bug which made the workaround for nRF52840 Anomaly 172 non-functional.

** Serialization **

- Fixed an issue with HCI transport sending redundant bytes on certain packet payloads containing escape codes.
- Fixes in serialization codecs.

*** Known Issues
****************

** General **

- Programming and debugging the nRF52811 chip may require an update of the J-Link firmware in order to recognize the new chip.
- The workaround for Anomaly 198 for nRF52840 SPIM3 peripheral that has been implemented in nrfx_spim cannot be used with a SoftDevice.
  Flag NRFX_SPIM3_NRF52840_ANOMALY_198_WORKAROUND_ENABLED must be set to zero.
  The workaround based on a dedicated RAM block for SPIM3 must be used instead.

** BLE **

- GATTC: the ble_gattc_service_t::uuid field is incorrectly populated in the BLE_GATTC_EVT_PRIM_SRVC_DISC_RSP event
  if the sd_ble_gattc_primary_services_discover() or sd_ble_gattc_read() are called when a Primary Service Discovery by Service UUID is already ongoing.
  When the application has called sd_ble_gattc_primary_services_discover(), it should wait for the BLE_GATTC_EVT_PRIM_SRVC_DISC_RSP event before calling sd_ble_gattc_primary_services_discover() or sd_ble_gattc_read().
- The TFTP Background DFU example has known instabilities.

** Drivers and libraries **

- The SAADC driver does not handle detection limits 'high' and 'low' correctly if SAADC resolution is greater than 10 bits.
- USBD:
  - The library may handle Remote Wakeup incorrectly.
  - Issuing a SET_ADDRESS(0) request does not cause the device to change its state to default.
  - The device does not STALL when a DATA transaction is received outside of SETUP. It ACKs instead.

** IoT **

- For Linux kernels >= 4.12, The BLE_6LOWPAN_LEGACY_MODE configuration parameter must be set to 0 (the default is 1).
  The default value must be kept for Linux kernels < 4.12.
  With this configuration set up incorrectly, the examples do not work and are difficult to debug.

======================================================================

nRF5 SDK v15.2.0
------------------------
Release Date: Week 37, 2018

This SDK release is an update replacing the non-published nRF5 SDK release v15.1.0.
The main updates compared to v15.1.0 are summarized in the last three points of the Highlights section.

Highlights:
 - Added support for the new SoftDevices S140, S132, and S112 v6.1.0.
 - Added new targets for running S112 on nRF52832 (PCA10040).
 - Updated ESB library to support all nRF52 devices (nRF52810, nRF52832 (Rev.1 & Rev.2), and nRF52840).
 - Updated SDFU to include nRF52810 target (PCA10040E).
 - Released nrf_log in production quality.
 - Removed the workaround in nrf_sdh.c overriding the default priority level on SWI interrupt SD_EVT_IRQn and RADIO_NOTIFICATION_IRQn used by the SoftDevice.
 - Changed the default interrupt priority level for the peripherals from 7 to 6. This is done to be aligned with the priority of the SWI coming from the SoftDevice.
 - Fixed an interoperability issue with some Windows 10 versions when bonded and using directed advertising.

Note: Due to compatibility issues, you must run the upgrade using nRF Connect Desktop v2.5.0 or later when testing the Bluetooth examples in nRF5 SDK v15.2.0.

The following toolchains/devices have been used for testing and verification:
 - ARM: MDK-ARM version 5.18a
 - GCC: GCC ARM Embedded 6.3 2017-q2-update
 - IAR: IAR Workbench 7.80.4 (IAR 8 - see note below)
 - SES: SES 3.40

*****
Note for IAR 8 users:
(Libraries for IAR 8 require wchar_t to be of size 32 bits while IAR 7 requires 16 bits).

To run a project using IAR 8, follow these intructions:
 - Open the IAR project in IAR 8. The IAR workbench will automatically generate an IAR 8 compatible project file.
 - If the project contains one of the precompiled libraries listed below, replace it with the IAR 8 compatible alternative
   (there are no projects targeting nRF51 in this SDK).
 - Save the project.
 - When building the project, you might get the warning: "The header file 'cmsis_iar.h' is obsolete and should not be used. [...]".
    - The problem is described in DevZone post: https://devzone.nordicsemi.com/f/nordic-q-a/31123/iar-ewarm-8-22-1-complains-about-cmsis_iar-h
      The solution is to remove all occurrences of #include <cmsis_iar.h>.

The affected libraries are:
 - micro-ecc crypto:
    - IAR7: Includes library located in the folder named “…_iar\…”.
    - IAR8: Switch to using the library from the folder named “…_armgcc\…”.
 - nrf_cc310, nrf_cc310_bl, and nrf_oberon:
    - IAR7: Includes the library where “_short_wchar_” is part of the file name.
    - IAR8: Switch to using the library with similar naming, but where the “short_wchar” is removed.
 - Gazell, NFC Tag, and 802.15.4:
    - IAR7: Includes the library where the file name ends with “_iar”.
    - IAR8: Switch to using the library with similar file name that ends with “_gcc”.
*****

Supported SoftDevices:
 - S112 v6.1.x
 - S132 v6.1.x
 - S140 v6.1.x
 - S212 v5.0.x

Supported boards:
 - PCA10040
 - PCA10040E (nRF52810 emulation on PCA10040)
 - PCA10056
 - PCA10059 (support in selected examples)
 - D52DK1 from Garmin Canada (only for ANT examples)

For other devices and boards, see the SDK documentation, section "Using
the SDK with other boards".

*** New features
*****************

** BLE **
 - Added new targets to demonstrate the use of S112 on nRF52832 (PCA10040).
 - Added "Property Read" for the Object Transfer Service client (ble_app_ots_c).
 - Added a Scanning Module to simplify scanning for BLE devices in central role.
 - Peer Manager:
    - peer_manager_handler.h: There are now standard event handlers available to users of the Peer Manager.
       The event handlers provide features like logging, automatically securing the link, and automatically
       deleting the oldest bond if the flash is full.
    - PM_RA_PROTECTION_ENABLED: The Peer Manager can now be configured to reject repeated security requests
       from peers that failed pairing.
    - PM_LESC_ENABLED: Improved LESC support.
    - PM_LOG_ENABLED: Added error and warning level logging messages to the Peer Manager.
    - PM_EVT_FLASH_GARBAGE_COLLECTION_FAILED: Added new event.
    - PM_PEER_DATA_ID_CENTRAL_ADDR_RES: Added automatic storing of the peer's Central Address Resolution value during bonding.
    - pm_peer_id_list(): Added a new function for creating lists of Peer IDs, including some filtering.
 - Added LESC support to the following examples: ble_app_hrs, ble_app_hrs_c, and ble_app_gls.
 - Added support for nRF52840 (PCA10056) in the beacon example (ble_app_beacon).
 - Added Swift Pair support to the HID mouse example (ble_app_hids_mouse).
 - Battery Service: Added the possibility to notify a reconnected, bonded peer of an updated battery level.
    This feature is demonstrated in the Immediate Alert Server example.

** Crypto **
 - EdDSA: Added support for Edwards-curve Digital Signature Algorithm (Ed25519).
 - In documentation, added a table showing supported nrf_crypto backends for different examples:
    http://infocenter.nordicsemi.com/topic/com.nordic.infocenter.sdk5.v15.2.0/nrf_crypto_default_backends.html

** DFU/Bootloader **
 - Added a new target to the SDFU example to demonstrate SDFU running on nRF52810 (PCA10040E). In a single bank update, there is only
    about 60 kB of flash available. This restricts what can be updated.
 - The bootloader settings page is now backed up before being updated. This increases protection from corruption caused by chance events
    (for example, power failure) and malicious apps.
 - The advertising interval of BLE DFU can now be configured in sdk_config (NRF_DFU_BLE_ADV_INTERVAL).
 - The size of the application data area that is left alone by the bootloader can now be configured
    in sdk_config (NRF_DFU_APP_DATA_AREA_SIZE).
 - The bootloader code now supports most of nrf_crypto backends. However, the size of the binary will likely be too large if other backends
    are used, so you will need to accomodate by increasing the size of the bootloader.

** USB **
 - Added response/no response to an IN token on ISO IN endpoint with a ZLP when no data is ready. This can be set with USBD_CONFIG_ISO_IN_ZLP.
 - Added support for configuration string ID.
 - Added an option to give priority to isochronous transfers using USBD_CONFIG_DMASCHEDULER_ISO_BOOST.
 - Implemented SOF event callback in interrupt for classes.
 - Added an enum and get function for a selected protocol (boot or report) in HID. Implemented a SET_PROTOCOL propagation mechanism using
    on_set_protocol methods. Buffers can now be cleared after the SET_PROTOCOL command using clear_buffer methods.
 - Redesigned the idle report mechanism in HID. It now allows a callback function and handles multiple report IDs.
 - Added an option to send a ZLP on write with the same size as the endpoint in CDC ACM class using APP_USBD_CDC_ACM_ZLP_ON_EPSIZE_WRITE.
 - Implemented macros to set interval for individual endpoints. See APP_USBD_EP_WITH_INTERVAL.
 - Transfers in Audio class can now be started in SOF interrupt set in the app_usbd_audio_sof_interrupt_register function.

*** Changes
************

** BLE **
 - Increased the length of the advertising name for the Running Speed and Cadence sensor example (ble_app_rscs) to make it easy to verify
    that it is using the extended advertising.
 - Included the Scanning module into all BLE examples. This aligns how scanning is performed in these examples.
 - Updated the NFC pairing examples (ble_app_hids_keyboard_pairing_nfc, ble_app_hrs_nfc_pairing, ble_nfc_pairing_reference) to start using
    the LESC functionality in the Peer Manager (which uses the nrf_ble_lesc module).
 - Removed the manual handling of credits for the Object Transfer Service (ble_app_ots and ble_app_ots_c). Most use cases now work faster
    and simpler when the SoftDevice is controlling it.
 - Updated the API documentation for advertising_init in the Advertising module (ble_advertising). It was clarified that UUID arrays were not
    copied into the Advertising module.
 - Advertising module (ble_advertising) is no longer dependent on the fstorage module.
 - Changed the ANCS example (ble_app_ancs_c) so that it no longer performs service discovery after connecting to an already bonded peer.
 - Lowered the advertising interval in the Eddystone example (ble_app_eddystone), because some advertising packets would be lost when combined
    with the timeslot API.
 - Reduced the maximum supported value for advertising interval in Eddystone from 20000 to 16384. If a higher value is set, the SoftDevice returns
    an error code that asserts the application.
 - Peer Manager:
    - Various improvements to documentation.
    - The Peer Manager will now take less space for the same features.
    - To decrease complexity, the Peer Manager no longer uses the 'reserve' functionality in FDS, meaning that PM_EVT_STORAGE_FULL
      events will come slightly later if bonds cannot be stored during bonding.
    - Error event parameters now specify whether the error code is to be interpreted as an FDS_ error or an NRF_ error.
    - Peers without a stored rank are now never returned from pm_peer_ranks_get().
    - The function pm_peer_data_load() now fills the array even when returning NRF_ERROR_DATA_SIZE.
    - Enabled internal LESC key handling through PM_LESC_ENABLED. Function pm_lesc_public_key_set() is now deprecated because of this change.
 - All examples using the Peer Manager now use the new standard event handlers.
    While some examples implement custom behavior, all examples do the following:
    - Log Peer Manager events (at different log levels).
    - Encrypt immediately on connection with bonded peers.
    - Delete old bonds to make room for new peer data.
 - Some examples supporting central mode disconnect when link encryption fails. Look for functions calling pm_handler_disconnect_on_sec_failure().
 - The ble_app_bms example will now request for security procedure to be initiated if the Central does not initiate it.
 - Updated examples with directed advertisement to take into account Central Address Resolution value.

** IEEE 802.15.4 **
 - Updated the radio test example to support 802.15.4 radio modes.

** Crypto **
 - Updated documentation about RAM requirements on mbed TLS.
 - Added endianness change Curve25519 (to little endian).
 - Removed the following defines. A compile error is shown if they are enabled in a configuration:
    - NRF_CRYPTO_BACKEND_CC310_BL_HASH_LITTLE_ENDIAN_DIGEST_ENABLED
    - NRF_CRYPTO_BACKEND_CC310_BL_ECC_LITTLE_ENDIAN_ENABLED
    - NRF_CRYPTO_BACKEND_MICRO_ECC_LITTLE_ENDIAN_ENABLED
    - NRF_CRYPTO_BACKEND_NRF_SW_HASH_LITTLE_ENDIAN_DIGEST_ENABLED
 - nrf_crypto micro-ecc backend: Moved ECDH public key validation from the key convert function to ECDH compute
    (moved from nrf_crypto_backend_micro_ecc_public_key_from_raw to nrf_crypto_backend_micro_ecc_ecdh_compute).
 - Upgraded nrf_cc310 and nrf_cc310_bl to version 0.9.10 including minor changes to some default configurations.
 - Removed micro-ecc library/mbed TLS from BLE LESC examples for better user experience.
    - micro-ecc library prevented a working compilation in a fresh LESC example (requires external download).
    - mbed TLS significantly increases compilation time in the project, even if it is not configured as the enabled nrf_crypto backend.

** DFU and Bootloader **
 - Updated documentation about how to change the existing SDFU project, so that the application can be uploaded without signature verification,
    but at the same time to keep the signature verification when updating a SoftDevice and/or bootloader.
 - The bootloader now does not use app_timer, which saves flash space.
 - The bootloader now does the endian-conversion in code, instead of relying on endian-conversion in nrf_crypto.

** Drivers and libraries **
 - Changed the peripherals' default interrupt priority level from 7 to 6.
 - Included new version of nrfx (v1.1.0). For the nrfx changelog, see https://github.com/NordicSemiconductor/nrfx/blob/master/CHANGELOG.md
 - nrf_log:
     - Updated to production quality.
     - You can now store/load the filtering configuration in FDS.
     - You can now control one backend from another.
 - nrf_cli: Added support for terminal meta keys.

** Proprietary **
 - Updated ESB library to support all current variants of nRF52. This mainly involves adding proper handling of Errata related to the radio.
 - Added a function to skip the next packet in the TX queue. This was previously a function used internally in the module under another name.

** USB **
 - Moved USBD strings configuration to sdk_config.
 - Rebuilt MSC class write procedure.
 - Moved APP_USBD_CONFIG_LOG_ENABLED to nrf_log settings.
 - HID report protocol is now default after reset.
 - HID default idle rate after reset can now be defined.
 - OUT transfers are now dropped when clearing stall on endpoint.
 - SET_ADDRESS command is now defined as a separate event in app_usbd. It does not change the state of the device anymore.
 - EP0 is now disabled until USB RESET condition is detected.
 - HID OUT reports are now limited to 63 bytes of data + 1 byte reserved for report ID.

*** Bug fixes
****************

** BLE **
 - Fixed a bug in the BLE UART client (ble_app_uart_c) where it would check the wrong error code when issuing multiple write commands.
 - Fixed a bug in the ANCS example (ble_app_ancs) where app_timer was included too many times.
 - Fixed a bug in the Advertising module (ble_advertising) where a comment referred to seconds instead of 10 ms.
 - Fixed a bug in the LESC connection example (ble_app_multirole_lesc) where the procedure for connection parameter update would not be started
    immediately upon connection.
 - Fixed a bug where a precompiled hex was missing for Immediate Alert Server (ble_app_ias) and Service Changed server (ble_app_gatts) examples.
 - Fixed a bug in the Radio Notification Event Handler (ble_radio_notification) where a missing include stopped it from compiling.
 - Fixed a bug in the BLE Interactive Command Line Interface Example in service discovery procedure.
 - Fixed a bug in the Alert Notification Service, where it was not possible to enable notifications for an unread alert.
 - Peer Manager:
    - Fixed a bug where the event PM_EVT_FLASH_GARBAGE_COLLECTED was also sent when garbage collection failed.
    - Fixed a bug in pm_next_peer_id_get() where it could report a peer with no data attached to it if used during bonding.
    - Fixed a bug where peer data would not be written because the internal retry mechanism failed after two attempts.
    - Fixed a bug where pairing (no bonding) could happen with an already bonded peer without triggering a PM_EVT_CONN_SEC_CONFIG_REQ event.
    - Fixed several documentation bugs related to error codes.
 - Eddystone:
    - Fixed a bug where the default TX power was set to 0 instead of using the DEFAULT_FRAME_TX_POWER define.
    - Fixed a bug where an invalid reference of a variable could cause incorrect data to be sent.

** IEEE 802.15.4 **
 - Adjusted CCA threshold value to be correct for nRF52840 Rev. 1 (different from what was available on the Engineering sample).
 - Implemented a fix for Anomaly 153 (temperature correction of RSSI measurement): added an API in RAL module for calculating the corrected RSSI value.

** Drivers and libraries **
 - Fixed a bug in the SPI manager where app_timer was included too many times.
 - Fixed a wrapping issue in the Ring Buffer library.

** DFU/Bootloader **
 - Fixed a bug where the watchdog feeding in the bootloader did not happen during a certain FW activation.

** DTM **
 - Added support for 8 dB on nRF52840 targets.
 - Implemented the workaround for nRF52840 Anomaly 172 which caused the device to fail a test with interference in co-channels (RF-PHY/RCV/BV-29-C).

** Proprietary **
 - Fixed a bug in bytewise_bit_swap where it was harder to backport the implementation to nRF51.
 - Fixed a bug in nrf_esb_pop_tx where the packet queue would occasionally be corrupted.
 - Added shutdown of the system timer as the workaround for Anomaly 78 and to save energy.

** NFC **
 - Integrated fixes from EMVCo test suite (improved interoperability).
 - Added automatic fix for Anomaly 181.
 - Fixed a bug where HFCLK was requested too early for nRF52840 Rev. 1 chip.
 - Changed the way the fixes for chip errata are switched: use chip defines from MDK instead of board defines (simplifying usage of custom boards).

** USB **
 - Removed redundant barriers in USBD HAL.
 - Fixed a bug in HID library where the report descriptor was limited to 64 bytes.
 - Fixed a bug where USBD was not able to wake up after SOF event.
 - Fixed a bug where the SET_ADDRESS command was not processed in time.
 - USB application library (stack) now properly supports a situation when the HOST requests a descriptor but sets wLength Setup field to 0.

*** Known Issues
****************

** BLE **
 - Peer Manager:
    - When a link is already secured and the peer sends a slave security request for a higher level of security, the request will not be honored.
    - Service Changed indications might be silently dropped without being sent if the attempt to send them happens during an ATT MTU exchange.
    - Service Changed indications might be silently dropped if the flash is full when the Service Changed flag is being stored in flash.

** BLE IOT **
 - Neighbor discovery module for lwIP requires the on-link flag in the router advertisement to be set to create a SLAAC address from the prefix.
    However, RFC 7668 (https://tools.ietf.org/html/rfc7668) requires this bit to be zero. Therefore, the nd6.c from lwIP source has been modified
    to relax this check.
 - There are some issues when using the IoT examples against Linux Kernel 4.12+ that cause the kernel to only work with one 6LoWPAN connection.
    If more than one kit is connected using 6LoWPAN, none of the nodes will be accessible.
 - Scheduler has been included in most IoT examples to avoid race conditions found when using the lwIP stack, more precisely the TCP examples.
    The issue was that the TCP client would stop working after about 15 hours. However, when using mbed TLS, the use of scheduler is not possible.
    Therefore, the MQTT client examples might be affected by this issue.
 - The use of security, both with TLS and DTLS, should be treated as experimental.
 - MQTT examples cannot be used with commissioning on nRF52832. There is not enough RAM to accommodate both TLS and the commissioning service.
 - If enabled, RTT logs in IoT bootloader might not be printed before resetting.
 - The background_dfu example does not work.

** Drivers and libraries **
 - SAADC driver is not handling detection limits: high and low correctly if SAADC resolution is greater than 10 bits.
 - In the radio test example, modulated packets will only have the requested content in the first two bytes.
    Further bytes have random values.
 - In the radio test example, start_duty_cycle_modulated_tx is not working as intended.
    The actual duty cycle on air is not what was requested in the command.

** USBD **
 - Due to Anomaly 199, the USBD driver blocks code execution during EasyDMA transfer (for stability).
 - USBD BLE UART FreeRTOS example is not working when combined with Nordic UART Service Client example.

========================================================================

nRF5 SDK v15.1.0
------------------------
Release Date: Week 34, 2018

Highlights:
 - Added support for the new SoftDevices S140, S132, and S112 v6.1.0.
 - Added new targets for running S112 on nRF52832 (PCA10040).
 - Updated ESB library to support all nRF52 devices (nRF52810, nRF52832 (Rev.1 & Rev.2), and nRF52840).
 - Updated SDFU to include nRF52810 target (PCA10040E).
 - Released nrf_log in production quality.

Note: Due to compatibility issues, you must run the upgrade using nRF Connect Desktop v2.5.0 or later when testing the Bluetooth examples in nRF5 SDK v15.1.0.

The following toolchains/devices have been used for testing and verification:
 - ARM: MDK-ARM version 5.18a
 - GCC: GCC ARM Embedded 6.3 2017-q2-update
 - IAR: IAR Workbench 7.80.4 (IAR 8 - see note below)
 - SES: SES 3.40

*****
Note for IAR 8 users:
(Libraries for IAR 8 require wchar_t to be of size 32 bits while IAR 7 requires 16 bits).

To run a project using IAR 8, follow these intructions:
 - Open the IAR project in IAR 8. The IAR workbench will automatically generate an IAR 8 compatible project file.
 - If the project contains one of the precompiled libraries listed below, replace it with the IAR 8 compatible alternative
   (there are no projects targeting nRF51 in this SDK).
 - Save the project.
 - When building the project, you might get the warning: "The header file 'cmsis_iar.h' is obsolete and should not be used. [...]".
	- The problem is described in DevZone post: https://devzone.nordicsemi.com/f/nordic-q-a/31123/iar-ewarm-8-22-1-complains-about-cmsis_iar-h
	  The solution is to remove all occurrences of #include <cmsis_iar.h>.

The affected libraries are:
 - micro-ecc crypto:
    - IAR7: Includes library located in the folder named “…_iar\…”.
    - IAR8: Switch to using the library from the folder named “…_armgcc\…”.
 - nrf_cc310, nrf_cc310_bl, and nrf_oberon:
    - IAR7: Includes the library where “_short_wchar_” is part of the file name.
    - IAR8: Switch to using the library with similar naming, but where the “short_wchar” is removed.
 - Gazell, NFC Tag, and 802.15.4:
    - IAR7: Includes the library where the file name ends with “_iar”.
    - IAR8: Switch to using the library with similar file name that ends with “_gcc”.
*****

Supported SoftDevices:
 - S112 v6.1.x
 - S132 v6.1.x
 - S140 v6.1.x
 - S212 v5.0.x

Supported boards:
 - PCA10040
 - PCA10040E (nRF52810 emulation on PCA10040)
 - PCA10056
 - PCA10059 (support in selected examples)
 - D52DK1 from Garmin Canada (only for ANT examples)

For other devices and boards, see the SDK documentation, section "Using
the SDK with other boards".

*** New features
*****************

** BLE **
 - Added new targets to demonstrate the use of S112 on nRF52832 (PCA10040).
 - Added "Property Read" for the Object Transfer Service client (ble_app_ots_c).
 - Added a Scanning Module to simplify scanning for BLE devices in central role.
 - Peer Manager:
	- peer_manager_handler.h: There are now standard event handlers available to users of the Peer Manager.
       The event handlers provide features like logging, automatically securing the link, and automatically
       deleting the oldest bond if the flash is full.
    - PM_RA_PROTECTION_ENABLED: The Peer Manager can now be configured to reject repeated security requests
       from peers that failed pairing.
    - PM_LESC_ENABLED: Improved LESC support.
    - PM_LOG_ENABLED: Added error and warning level logging messages to the Peer Manager.
    - PM_EVT_FLASH_GARBAGE_COLLECTION_FAILED: Added new event.
 - Added LESC support to the following examples: ble_app_hrs, ble_app_hrs_c, and ble_app_gls.
 - Added support for nRF52840 (PCA10056) in the beacon example (ble_app_beacon).
 - Added Swift Pair support to the HID mouse example (ble_app_hids_mouse).
 - Battery Service: Added the possibility to notify a reconnected, bonded peer of an updated battery level.
    This feature is demonstrated in the Immediate Alert Server example.

** Crypto **
 - EdDSA: Added support for Edwards-curve Digital Signature Algorithm (Ed25519).
 - In documentation, added a table showing supported nrf_crypto backends for different examples:
    http://infocenter.nordicsemi.com/topic/com.nordic.infocenter.sdk5.v15.1.0/nrf_crypto_default_backends.html

** DFU/Bootloader **
 - Added a new target to the SDFU example to demonstrate SDFU running on nRF52810 (PCA10040E). In a single bank update, there is only
    about 60 kB of flash available. This restricts what can be updated.
 - The bootloader settings page is now backed up before being updated. This increases protection from corruption caused by chance events
	(for example, power failure) and malicious apps.
 - The advertising interval of BLE DFU can now be configured in sdk_config (NRF_DFU_BLE_ADV_INTERVAL).
 - The size of the application data area that is left alone by the bootloader can now be configured
    in sdk_config (NRF_DFU_APP_DATA_AREA_SIZE).
 - The bootloader code now supports most of nrf_crypto backends. However, the size of the binary will likely be too large if other backends
    are used, so you will need to accomodate by increasing the size of the bootloader.

** USB **
 - Added response/no response to an IN token on ISO IN endpoint with a ZLP when no data is ready. This can be set with USBD_CONFIG_ISO_IN_ZLP.
 - Added support for configuration string ID.
 - Added an option to give priority to isochronous transfers using USBD_CONFIG_DMASCHEDULER_ISO_BOOST.
 - Implemented SOF event callback in interrupt for classes.
 - Added an enum and get function for a selected protocol (boot or report) in HID. Implemented a SET_PROTOCOL propagation mechanism using
	on_set_protocol methods. Buffers can now be cleared after the SET_PROTOCOL command using clear_buffer methods.
 - Redesigned the idle report mechanism in HID. It now allows a callback function and handles multiple report IDs.
 - Added an option to send a ZLP on write with the same size as the endpoint in CDC ACM class using APP_USBD_CDC_ACM_ZLP_ON_EPSIZE_WRITE.
 - Implemented macros to set interval for individual endpoints. See APP_USBD_EP_WITH_INTERVAL.
 - Transfers in Audio class can now be started in SOF interrupt set in the app_usbd_audio_sof_interrupt_register function.

*** Changes
************

** BLE **
 - Increased the length of the advertising name for the Running Speed and Cadence sensor example (ble_app_rscs) to make it easy to verify
	that it is using the extended advertising.
 - Included the Scanning module into all BLE examples. This aligns how scanning is performed in these examples.
 - Updated the NFC pairing examples (ble_app_hids_keyboard_pairing_nfc, ble_app_hrs_nfc_pairing, ble_nfc_pairing_reference) to start using
	the LESC functionality in the Peer Manager (which uses the nrf_ble_lesc module).
 - Removed the manual handling of credits for the Object Transfer Service (ble_app_ots and ble_app_ots_c). Most use cases now work faster
	and simpler when the SoftDevice is controlling it.
 - Updated the API documentation for advertising_init in the Advertising module (ble_advertising). It was clarified that UUID arrays were not
	copied into the Advertising module.
 - Advertising module (ble_advertising) is no longer dependent on the fstorage module.
 - Changed the ANCS example (ble_app_ancs_c) so that it no longer performs service discovery after connecting to an already bonded peer.
 - Lowered the advertising interval in the Eddystone example (ble_app_eddystone), because some advertising packets would be lost when combined
	with the timeslot API.
 - Reduced the maximum supported value for advertising interval in Eddystone from 20000 to 16384. If a higher value is set, the SoftDevice returns
	an error code that asserts the application.
 - Peer Manager:
	- Various improvements to documentation.
	- The Peer Manager will now take less space for the same features.
	- To decrease complexity, the Peer Manager no longer uses the 'reserve' functionality in FDS, meaning that PM_EVT_STORAGE_FULL
      events will come slightly later if bonds cannot be stored during bonding.
	- Error event parameters now specify whether the error code is to be interpreted as an FDS_ error or an NRF_ error.
	- Peers without a stored rank are now never returned from pm_peer_ranks_get().
	- The function pm_peer_data_load() now fills the array even when returning NRF_ERROR_DATA_SIZE.
	- Enabled internal LESC key handling through PM_LESC_ENABLED. Function pm_lesc_public_key_set() is now deprecated because of this change.
 - All examples using the Peer Manager now use the new standard event handlers.
    While some examples implement custom behavior, all examples do the following:
    - Log Peer Manager events (at different log levels).
    - Encrypt immediately on connection with bonded peers.
    - Delete old bonds to make room for new peer data.
 - Some examples supporting central mode disconnect when link encryption fails. Look for functions calling pm_handler_disconnect_on_sec_failure().
 - The ble_app_bms example will now request for security procedure to be initiated if the Central does not initiate it.

** IEEE 802.15.4 **
 - Updated the radio test example to support 802.15.4 radio modes.

** Crypto **
 - Updated documentation about RAM requirements on mbed TLS.
 - Added endianness change Curve25519 (to little endian).
 - Removed the following defines. A compile error is shown if they are enabled in a configuration:
	- NRF_CRYPTO_BACKEND_CC310_BL_HASH_LITTLE_ENDIAN_DIGEST_ENABLED
	- NRF_CRYPTO_BACKEND_CC310_BL_ECC_LITTLE_ENDIAN_ENABLED
	- NRF_CRYPTO_BACKEND_MICRO_ECC_LITTLE_ENDIAN_ENABLED
	- NRF_CRYPTO_BACKEND_NRF_SW_HASH_LITTLE_ENDIAN_DIGEST_ENABLED
 - nrf_crypto micro-ecc backend: Moved ECDH public key validation from the key convert function to ECDH compute
	(moved from nrf_crypto_backend_micro_ecc_public_key_from_raw to nrf_crypto_backend_micro_ecc_ecdh_compute).
 - Upgraded nrf_cc310 and nrf_cc310_bl to version 0.9.10 including minor changes to some default configurations.

** DFU and Bootloader **
 - Updated documentation about how to change the existing SDFU project, so that the application can be uploaded without signature verification,
	but at the same time to keep the signature verification when updating a SoftDevice and/or bootloader.
 - The bootloader now does not use app_timer, which saves flash space.
 - The bootloader now does the endian-conversion in code, instead of relying on endian-conversion in nrf_crypto.

** Drivers and libraries **
 - Included new version of nrfx (v1.1.0). For the nrfx changelog, see https://github.com/NordicSemiconductor/nrfx/blob/master/CHANGELOG.md
 - nrf_log:
     - Updated to production quality.
     - You can now store/load the filtering configuration in FDS.
	 - You can now control one backend from another.
 - nrf_cli: Added support for terminal meta keys.

** Proprietary **
 - Updated ESB library to support all current variants of nRF52. This mainly involves adding proper handling of Errata related to the radio.
 - Added a function to skip the next packet in the TX queue. This was previously a function used internally in the module under another name.

** USB **
 - Moved USBD strings configuration to sdk_config.
 - Rebuilt MSC class write procedure.
 - Moved APP_USBD_CONFIG_LOG_ENABLED to nrf_log settings.
 - HID report protocol is now default after reset.
 - HID default idle rate after reset can now be defined.
 - OUT transfers are now dropped when clearing stall on endpoint.
 - SET_ADDRESS command is now defined as a separate event in app_usbd. It does not change the state of the device anymore.
 - EP0 is now disabled until USB RESET condition is detected.
 - HID OUT reports are now limited to 63 bytes of data + 1 byte reserved for report ID.

*** Bug fixes
****************

** BLE **
 - Fixed a bug in the BLE UART client (ble_app_uart_c) where it would check the wrong error code when issuing multiple write commands.
 - Fixed a bug in the Eddystone example (ble_app_eddystone) where the default TX power was set to 0 directly
	instead of using the DEFAULT_FRAME_TX_POWER define.
 - Fixed a bug in the ANCS example (ble_app_ancs) where app_timer was included too many times.
 - Fixed a bug in the Advertising module (ble_advertising) where a comment referred to seconds instead of 10 ms.
 - Fixed a bug in the LESC connection example (ble_app_multirole_lesc) where the procedure for connection parameter update would not be started
	immediately upon connection.
 - Fixed a bug where a precompiled hex was missing for Immediate Alert Server (ble_app_ias) and Service Changed server (ble_app_gatts) examples.
 - Fixed a bug in the Radio Notification Event Handler (ble_radio_notification) where a missing include stopped it from compiling.
 - Fixed a bug in the BLE Interactive Command Line Interface Example in service discovery procedure.
 - Fixed a bug in the Alert Notification Service, where it was not possible to enable notifications for an unread alert.
 - Peer Manager:
    - Fixed a bug where the event PM_EVT_FLASH_GARBAGE_COLLECTED was also sent when garbage collection failed.
    - Fixed a bug in pm_next_peer_id_get() where it could report a peer with no data attached to it if used during bonding.
	- Fixed a bug where peer data would not be written because the internal retry mechanism failed after two attempts.
    - Fixed several documentation bugs related to error codes.

** IEEE 802.15.4 **
 - Adjusted CCA threshold value to be correct for nRF52840 Rev. 1 (different from what was available on the Engineering sample).
 - Implemented a fix for Anomaly 153 (temperature correction of RSSI measurement): added an API in RAL module for calculating the corrected RSSI value.

** Drivers and libraries **
 - Fixed a bug in the SPI manager where app_timer was included too many times.
 - Fixed a wrapping issue in the Ring Buffer library.

** DTM **
 - Added support for 8 dB on nRF52840 targets.
 - Implemented the workaround for nRF52840 Anomaly 172 which caused the device to fail a test with interference in co-channels (RF-PHY/RCV/BV-29-C).

** Proprietary **
 - Fixed a bug in bytewise_bit_swap where it was harder to backport the implementation to nRF51.
 - Fixed a bug in nrf_esb_pop_tx where the packet queue would occasionally be corrupted.
 - Added shutdown of the system timer as the workaround for Anomaly 78 and to save energy.

** NFC **
 - Integrated fixes from EMVCo test suite (improved interoperability).
 - Added automatic fix for Anomaly 181.
 - Fixed a bug where HFCLK was requested too early for nRF52840 Rev. 1 chip.
 - Changed the way the fixes for chip errata are switched: use chip defines from MDK instead of board defines (simplifying usage of custom boards).

** USB **
 - Removed redundant barriers in USBD HAL.
 - Fixed a bug in HID library where the report descriptor was limited to 64 bytes.
 - Fixed a bug where USBD was not able to wake up after SOF event.
 - Fixed a bug where the SET_ADDRESS command was not processed in time.

*** Known Issues
****************

** BLE **
 - Peer Manager:
	- When a link is already secured and the peer sends a slave security request for a higher level of security, the request will not be honored.
	- Service Changed indications might be silently dropped without being sent if the attempt to send them happens during an ATT MTU exchange.

** BLE IOT **
 - Neighbor discovery module for lwIP requires the on-link flag in the router advertisement to be set to create a SLAAC address from the prefix.
	However, RFC 7668 (https://tools.ietf.org/html/rfc7668) requires this bit to be zero. Therefore, the nd6.c from lwIP source has been modified
	to relax this check.
 - There are some issues when using the IoT examples against Linux Kernel 4.12+ that cause the kernel to only work with one 6LoWPAN connection.
	If more than one kit is connected using 6LoWPAN, none of the nodes will be accessible.
 - Scheduler has been included in most IoT examples to avoid race conditions found when using the lwIP stack, more precisely the TCP examples.
	The issue was that the TCP client would stop working after about 15 hours. However, when using mbed TLS, the use of scheduler is not possible.
	Therefore, the MQTT client examples might be affected by this issue.
 - The use of security, both with TLS and DTLS, should be treated as experimental.
 - MQTT examples cannot be used with commissioning on nRF52832. There is not enough RAM to accommodate both TLS and the commissioning service.
 - If enabled, RTT logs in IoT bootloader might not be printed before resetting.
 - The background_dfu example does not work.

** Drivers and libraries **
 - SAADC driver is not handling detection limits: high and low correctly if SAADC resolution is greater than 10 bits.
 - In the radio test example, modulated packets will only have the requested content in the first two bytes.
    Further bytes have random values.
 - In the radio test example, start_duty_cycle_modulated_tx is not working as intended.
    The actual duty cycle on air is not what was requested in the command.

** USBD **
 - Due to Anomaly 199, the USBD driver blocks code execution during EasyDMA transfer (for stability).

========================================================================

nRF5 SDK v15.0.0
------------------------
Release Date: Week 12, 2018

Highlights:
- Full support for nRF52840 and production quality of libraries and examples for this device.
- Support for the new SoftDevices S140, S132, and S112 v6.0.0.
- Peripheral drivers now use nrfx.
- Extensive rework of the DFU functionality.
- Extensive rework of the cryptography library (nrf_crypto).
- USB firmware is now in production quality.
- Serialization of SoftDevices S140, S132, and S112 v6.0.0.
- IEEE 802.15.4 protocol in production quality.
- Included nrf_oberon crypto library with standard Nordic 5-clause license.

The following toolchains/devices have been used for testing and
verification:
- ARM: MDK-ARM version 5.18a
- GCC: GCC ARM Embedded 6.3 2017-q2-update
- IAR: IAR Workbench 7.80.4 (IAR 8 - see note below)
- SES: SES 3.34
- Linux: Ubuntu 17.04, Kernel 4.10.0.
- Jlink: 6.22g
    
*****
Note for IAR 8 users:
Libraries for IAR 8 require wchar_t to be of size 32 bits while IAR 7 requires 16 bits.
To run a project using IAR 8, follow these intructions:
 - Open the IAR project in IAR 8. The IAR workbench will automatically generate an IAR 8 compatible project file.
 - If the project contains one of the precompiled libraries listed below, replace it with the IAR 8 compatible alternative
   (there are no projects targeting nRF51 in this SDK).
 - Save the project.
 - When building the project, you might get the warning: "The header file 'cmsis_iar.h' is obsolete and should not be used. ....".
   The problem is described in DevZone post: https://devzone.nordicsemi.com/f/nordic-q-a/31123/iar-ewarm-8-22-1-complains-about-cmsis_iar-h
   The solution is to remove all occurrences of #include <cmsis_iar.h>.

The affected libraries are
- micro-ecc crypto:
    - IAR 7: Includes the library located in the folder named "…_iar\…".
    - IAR 8: Switch to using the library from the folder named "…_armgcc\…".
- nrf_cc310, nrf_cc310_bl, and nrf_oberon:
    - IAR 7: Includes the library where "_short_wchar_" is part of the file name.
    - IAR 8: Switch to using the library with similar naming, but where the "short_wchar" is removed.
- Gazell, NFC Tag, and 802.15.4:
    - IAR 7: Includes the library where the file name ends with "_iar".
    - IAR 8: Switch to using the library with similar file name that ends with "_gcc".
*****
 
Supported SoftDevices:
- S112 v6.0.x
- S132 v6.0.x
- S140 v6.0.0
- S212 v5.0.x
     
Supported boards:
- PCA10040
- PCA10040E (nRF52810 emulation on PCA10040)
- PCA10056
- PCA10059 (support in selected examples)
- Dynastream's D52DK1 (only for ANT examples)
     
For other devices and boards, see the SDK documentation, section "Using
the SDK with other boards".
     
 
*** New features
*****************
 
** IEEE 802.15.4 **
 - Added support for SES toolchain.
 
** ANT **
 - Added support for SES and GCC toolchains in the following examples:
    - ANT-FS Client
    - ANT Bootloader/DFU
 
** BLE **
 - Added support for the new SoftDevices S140, S132, and S112 v6.0.0. For more information about SoftDevice v6.0.0, refer to the SoftDevice documentation.
 - Extended advertising and selection of advertising PHYs can now be configured using the advertising module (ble_advertising).
 - Running Speed and Cadence Service Application (ble_app_rscs) now advertises using extended advertising. Note that this makes it incompatible with devices that do not support extended advertising.
 - Added multilink support for a selected group of BLE services (including separate GATT context for each connected client).
    - Affected services:
        - Human Interface Device Service: ble_hids.
        - Nordic UART Service: ble_nus.
        - Immediate Alert Service: ble_ias.
        - Battery Service: ble_bas.
    - Added BLE Link Context Manager module
    - Modified the Immediate Alert Application to show this feature.
 - Added a new application: BLE Interactive Command Line Interface Example.
 - Added Device Information Service client. This module can be used to read any characteristic of Device Information Service.
    - Modified the Running Speed and Cadence Collector example application (ble_app_rscs) to show the use of this module.
 - Immediate Alert Service client example application (ble_app_ias_c) is no longer experimental.
 - Immediate Alert Service server example application (ble_app_ias) is no longer experimental.
 - GATT Service Client Example Application (ble_app_gatts_c) is no longer experimental.
 - GATT Service Server Example Application (ble_app_gatts) is no longer experimental.
 - Improved the test description documentation for Continuous Glucose Monitoring Service Example Application (ble_app_cgms). It now showcases more capabilities of the application and how to test them.
 - ble_conn_state: Added new function ble_conn_state_for_each_set_user_flag() which calls a function for each flag in a collection that is set.
 - Peer Manager:
    - Two new configuration parameters to disable functionality to save space:
        - PM_SERVICE_CHANGED_ENABLED to enable/disable Service Changed sending. This must be enabled if Service Changed is enabled in the GATT database.
        - PM_PEER_RANKS_ENABLED to enable/disable the tracking of peer ranks.
    - The relevant APIs have gained the error code NRF_ERROR_NOT_SUPPORTED if the function is called when the configuration is disabled.
 - Added NRF_SDH_BLE_GAP_DATA_LENGTH configuration (under nrf_sdh_ble) to configure BLE data length negotiated by the nrf_ble_gatt module.
 - Added BLE LESC module as experimental.
 
** BLE IOT **
 - Added support for the nRF52840 (PCA10056 board) with the use of the S140 SoftDevice.
 
** NFC **
 - Added support for SES toolchain in the Adafruit Tag Reader Example.

** Crypto **
 - Production quality nrf_crypto interface that supports software and hardware backends (using the CC310 hardware accelarator in nRF52840 devices).
 - nrf_crypto API supports the following cryptographic family of algorithms (subject to support in nrf_crypto backends):
    - AES (CBC, CTR, CFB, ECB, CBC_MAC, CMAC)
    - AEAD (CCM, CCM*, EAX, GCM, ChaCha-Poly)
    - ECC (Elliptic Curve Cryptography)
        - Key generation
        - Key validation
        - Key conversions (from/to raw format)
    - ECDH (multiple curves)
    - ECDSA (multiple curves)
    - SHA-2 family hash
    - HMAC
    - HKDF
    - RNG using AES CTR or through dedicated hardware/sofware (on nRF52840)
    - Experimental Ed25519 support (available through the nrf_crypto_ecdsa API)
 - nrf_crypto API support for dynamic memory management by configuration:
    - User-specified macros to NRF_CRYPTO_ALLOC and NRF_CRYPTO_FREE
    - Stack allocation (using alloca)
    - C dynamic allocation (malloc)
    - SDK Memory Manager (nrf_malloc)
 - nrf_crypto backends include the following:
    - Cifra
    - mbed TLS
    - micro-ecc
    - nrf_cc310
    - nrf_cc310_bl (code size optimized, to use in Secure DFU)
    - nRF HW (for RNG)
    - nrf_oberon
    - nRF software (legacy)
 - Examples of nrf_crypto usage with the option to change the nrf_crypto backends.
 - Test example to verify the cryptographic routines and APIs through standardized test vectors.
 
** DFU/Bootloader **
 - SoftDevice independence:
     - Only the BLE bootloader is now dependent on the SoftDevice. The others depend only on the MBR (which is now part of the SDK).
     - The DFU now supports updating applications that do not use the SoftDevice. Such an application must be compiled to be placed above the MBR.
 - The DFU protocol has been extended to support new messages:
     - Protocol version - To retrieve information about the protocol version.
     - Firmware version - To retrieve information (size, version) about each piece of firmware on the chip.
     - Hardware version - To retrieve information (flash/RAM size, page size) about the hardware.
     - DFU Abort - To instruct the bootloader to abort the DFU procedure and reset the device.
 - Configurable security: New configuration parameters to turn on and off version checking and signature checking of application transfers. Added a new example using the new configurations (open_bootloader).
 - DFU Trigger (USB): Added a library to allow DFU mode to be triggered through USB in the application. The library is used in the new ble_connectivity example that uses USB CDC ACM.
 - Added optional skipping of application CRC check. CRC check can be skipped on wakeup from System Off or on special value written to GPREGRET2 register.
 - Added watchdog support to the bootloader. If application had enabled watchdog before resetting to the bootloader, it is fed in the bootloader.
 
 ** Drivers and libraries **
 - Added support for wildcards in the CLI module.
 - Added TWI sensor module.
 - Added drivers for sensors on Thingy:52 (LPS22HB, BH1745, HTS221, CCS811, SX1509B, LIS2DH12).
 - Added the nrfx project as a set of default drivers and provided a legacy layer for supporting deprecated API.
 - Added support for filtering log messages on instance level in the logger module. Instance level logging added to nrf_balloc, nrf_queue, and nrf_atfifo.
 - Added new logger backends for writing logs to flash: flashlog backend for storing logs in standard operation, crashlog backend for dumping logs on error condition. Added CLI commands for controlling data stored in flash.
 - Added optional timestamp formatting in the logger. 
 - Added new implementation of app_timer (libraries/timer/experimental/app_timer2.c) which does not use SWI, uses less RAM and flash, and has modular, simpler design. It shares the same API as the legacy implementation. The new implementation is used by bootloaders and peripheral/CLI.
 - Added bsp_cli module to send BSP events through CLI.
 - Added nrf_atflags module for atomic manipulation of bit fields.
 - Added improved CLI UART backend called libUARTE. This backend is recommended when the CLI must exchange big amounts of data fast, for example when CLI is used with a script.
 
** Serialization **
 - Added serialization of the S112, S132, and S140 v6.0.0 SoftDevices.
 - Added serialization connectivity application for PCA10059 using USB CDC ACM as the transport layer.
 
** USB **
 - Added example with the SoftDevice and USB (usbd_ble_uart).
 - Added configuration of the self-powered descriptor bit (APP_USBD_CONFIG_SELF_POWERED).
 - Added buffering of transfers in CDC.
 - Added configuration of power in a descriptor (APP_USBD_CONFIG_MAX_POWER).
 - Added option to specify the CDC ACM protocol.
 - Added dummy interface class.
 - Implemented USBD power event processing in app_usbd event queue.
 - Implemented different ways of processing SOF events:
    - Normal - SOF events are pushed normally into the event queue.
    - Compress - SOF events are counted and bound with other events or executed when the queue is empty. This prevents the queue from filling up with SOF events.
    - Interrupt - SOF events are processed in the interrupt.
 - Implemented Get Output Report in HID class.
 - New SoftDevice API used for USB power events.
 - Button events can now be sent through CLI in the usbd_cdc_acm, usbd_hid_composide, and usbd_hid generic examples.
 
 
*** Changes
************
 
** ANT **
 - Added welcome message to all ANT examples. Logging is enabled by default in all of them.
 - Removed obsolete module: ant_stack_config. The ANT SoftDevice Handler module has taken over its functionality.
 
** BLE **
 - Minor improvements to consistency of BLE examples main functions (comments, function call ordering, function names).
 - BLE examples changed to use the Queued Write module (nrf_ble_qwr). Applications must explicitly configure characteristics to accept long writes. See app_ble_qwr for an example of this. This fixes a problem where peers could cause our devices to assert by issuing long writes.
 - BLE examples changed to use the Power Management library. Most examples now call nrf_pwr_mgmt_run() instead of sd_app_evt_wait().
 - Eddystone modules have been moved from components/libraries to components/ble.
 - ble_app_uart changed to have 247-byte MTU, up from 64.
 - Peer Manager:
     - The members of pm_conn_sec_procedure_t have been renamed from PM_LINK_SECURED_PROCEDURE_* to PM_CONN_SEC_PROCEDURE_*.
     - The following functions have gained new error codes:
         - pm_conn_secure()
         - pm_peer_data_store()
         - pm_peer_ranks_get()
         - pm_peer_rank_highest()
 
** BLE IOT **
 - Minor updates in TFTP background DFU modules to align with changed DFU libraries.
 
** Crypto **
 - nrf_crypto APIs have been changed to use big-endian only.
    - Previous versions of nrf_crypto used little-endian ordering to conform to BLE requirements in LESC.
      This has now been changed to big-endian everywhere. There are conversion functions available to
      change between little-endian and big-endian input/output.
    - See the Migration Guide for details.
 - nrf_crypto memory management has changed extensively.
    - See the Migration Guide for details.
 - nrf_crypto configuration of frontends and backends is now primarily done through sdk_config.h.
    - See the Migration Guide for details.
 
** DFU/Bootloader **
 - Configuration parameters (sdk_config) have changed. See the Migration Guide for details.
 - Refactoring: The DFU/bootloader code has been extensively refactored.
     - The split between DFU and bootloader has been improved.
        - New events from DFU.
        - Resetting has been moved from DFU to bootloader, based on DFU events.
        - Much of the code in nrf_dfu_utils has been extracted into the new nrf_bootloader_fw_activation and nrf_bootloader_dfu_timers modules.
     - Request handling module:
        - The dfu_req_handling module has been renamed to nrf_dfu_req_handler and moved to components/libraries/bootloader/dfu.
        - The request handling now uses app_scheduler and is entirely asynchronous and executed in the main context.
        - The init command validation was refactored out and into two new modules nrf_dfu_validation and nrf_dfu_ver_validation.
     - The Serial transport is now called UART.
     - The shared parts of the USB and UART transports have been placed in a separate module nrf_dfu_serial.
     - Most of the assembly code in bootloader_app_start has been replaced with C code and extracted into a separate file nrf_bootloader_app_start_final.
     - Examples:
        - The secure bootloader examples have been moved into a 'secure_bootloader' folder.
        - The experimental ANT bootloader has been moved into an 'experimental' folder.
        - The USB secure bootloader is no longer experimental.
 - Bootloader examples have been reorganized. Examples "bootloader_secure_ble", "bootloader_secure_serial", and "experimental_bootloader_secure_usb" have been merged into "secure_bootloader" with projects for each transport and board.
 - Write protection of the bootloader: Before booting the app, the bootloader will write-protect the flash areas of the bootloader and MBR (using BPROT on nRF52832/nRF52810 and ACL on nRF52840).
     - The BLE Buttonless SVCI interface needs access to the bootloader settings page from the application, so there is a new configuration parameter to specify whether that page should be part of the protection.
     - The SVCI interface will now return NRF_ERROR_FORBIDDEN if using the interface when the page is protected.
 - WDT compatibility: The bootloader will feed the WDT if the app has started it.
 - BLE DFU:
     - The BLE DFU bootloader now explicitly requests the preferred connection interval upon connection. The minimum and maximum connection intervals can be set in sdk_config.h.
     - The BLE DFU bootloader will use long ATT MTUs and data length extension when the host supports these features. This increases DFU transfer speed considerably.
     - Several stability improvements over different transport configurations.
 - USB serial number: The serial number of the USB bootloaders has changed to be the same as the default BLE address (found under DEVICEADDR in FICR).
 - New crypto backend for nRF52840: The bootloaders for nRF52840 use the hardware crypto backend (CC310) instead of micro-ecc.
 
** Drivers and libraries **
 - The way peripheral drivers are handled in the SDK has been reorganized:
     - Replaced existing drivers with the "external" drivers from nrfx project. See https://github.com/NordicSemiconductor/nrfx/blob/master/README.md for more information on nrfx.
     - New drivers from nrfx are located in "..\modules\nrfx".
     - Drivers replaced by nrfx are removed from "..\components\driver_nrf".
     - A glue layer is added to make the nrfx driver compatible with SDK and the SoftDevice.
 - Refactored I2S driver.
 - New reliable delay implementation.
 - Added CLI commands to nrf_balloc and nrf_queue which print out the status of all instances present in the system.
 - CLI built-in root commands: cli_stats, colors, and echo have been changed to subcommands: cli colors, cli echo, and cli stats.
 - The CMSIS-SVD files with device descriptions have been moved from the "..\svd" folder to the "..\modules\nrfx\mdk" folder.
 - Infineon OPTIGA:
     - Replaced "crypto\ifx_optiga_auth" example with the new one: "crypto\ifx_optiga_ecdsa_simple".
     - Updated related libraries from the "external\infineon" directory.
     - Replaced support for Infineon OPTIGA Trust E HSM with Infineon OPTIGA Trust X HSM.
     - Added support for IAR toolchain.
 
** Proprietary **
 - New Gazell functionalities:
     - Transmission statistics gathering - counts successful packet transactions and timeouts on each of the RF channels.
     - External analog frontend module control - generates TX/RX signals during transmission/receiving, which can be used to control the external PA/LNA module.
 - Updated gzll_ack_payload examples with the example usage of the new Gazell features.
 - Dynamic changes of TX attempts and TX power parameters are now allowed when the Gazell stack is enabled.
 - Removed the nRF52840 project from ble_app_gzll example (removed "pca10056" folder).
 
** NFC **
 - Type 2 Tag Library:
    - Modified Dynamic Memory structure of the Tag. Added Terminator TLV to indicate that there is no more relevant user data after NDEF TLV.
 - Type 4 Tag HAL:
    - Modified Frame Wait Time setting to support full range available on the nRF52840 Rev. 1 chip.
 - Type 4 Tag Library:
    - Modified behavior of the NFC_T4T_EVENT_NDEF_READ event: the event is always triggered when the last byte of the NDEF File is sent to an NFC Reader device - even if the Reader repeats the read operation multiple times in one session, i.e. before the Reader sends a DESELECT or SLP_REQ frame.
 - NFC BLE pairing library: modified to support multiple connections.
 - BLE/NFC examples: updated application behavior to comply with NFC Forum user experience recommendations.
 - NFC libraries which can enable nrf_log independently (using sdk_config.h) register the logger instance conditionally, i.e. only if nrf_log is enabled in the sdk_config.h
 
** USB **
 - app_usbd_init: when called with NULL configuration structure or NULL ev_handler member of a structure, the default event handler will be used.
 - app_usbd_init: removed clock initialization.
 - Descriptors are now generated on the fly using simple stackless thread code.
 - Added a warning for wrong interface order.
 - Combined USB CDC ACM driver for all examples into one.
 
   
*** Bugfixes
****************
 
** ANT **
 - Added missing logger backends to all examples.
 
** BLE **
  - Fixed a bug in ble_app_uart where Data Length update requests would be handled twice.
  - Fixed a bug in ble_app_uart and ble_app_uart_c where the "start" message in the main function was not followed by a line feed. This could make the applications seem unresponsive.
  - Fixed a bug in ble_app_cgms where properties of the characteristics were not configured.
  - Fixed a bug in ble_app_cgms where directed advertising was enabled by the advertising module but was ignored by the application. Directed advertising is now disabled.
  - Fixed a bug in ble_app_cgms where advertising was triggered twice when deleting bonds. The second call to advertising start would cause the example to assert on the busy error.
  - Fixed a bug in ble_app_gls  where the seconds field of the glucose measurement was never updated.
  - Fixed a bug in ble_tps where documentation for ble_tps_tx_power_level_set() was describing another unrelated function.
  - Fixed a bug in most main.c files where fds garbage collection fds_gc() would retry upon returning FDS_ERR_BUSY. However, this function call will never return FDS_ERR_BUSY.
  - Fixed a bug in nrf_ble_gatts_c where setting NRF_LOG_DEFAULT_LEVEL to debug (4) would cause an assert because it was not registered with the logger module (NRF_LOG_MODULE_REGISTER();)
  - Added missing Errata workaround to Direct Test Mode (DTM) on nRF52840.
  - Peer Manager:
      - Fixed the bonded flag in pm_conn_sec_status_get().
      - Fixed a performance bug in peer_database.c.
      - Split the error code NRF_ERROR_INVALID_STATE from pm_conn_secure() that could have two different meanings.
 
** BLE IOT **
  - Corrected logging module name, such that logs could be enabled in the LWIP platform module.
  - Fixed a reassembly bug in BSD socket module.
  - Fixed flushing of ports when the kit disconnects. Added API to flush the ports.
  - Added handling of BLE_L2CAP_EVT_CH_SDU_BUF_RELEASED event to generate the BLE_IPSP_EVT_CHANNEL_DATA_TX_COMPLETE in case link disconnection occured before the TX was complete.
  - Resolved an issue with MQTT/lwIP packets stuck in a TX queue. Now forcing out enqueued data before close.
  - Conformed to MQTT specification in the use of QoS flag in MQTT connect.
 
** DFU/Bootloader **
  - Bootloaders for nRF52840 now support bootloader updates (if used with the new MBR or SoftDevice).
  
** Drivers and libraries **
  - Extended input pin configuration in the GPIOTE driver: configuration of GPIOTE INPUT pin added, which does not change the current GPIO configuration.
  - CLI module - fixed echo command behavior. When echo is off, the command will not be printed after log print.
  - Logger modules - stability fixes (including https://devzone.nordicsemi.com/f/nordic-q-a/31178/bug-nrf_log_frontend-m_log_data-buffer-overflow).
  - More changes in drivers can be found in the modules/nrfx directory in the CHANGELOG.md file.

** Proprietary **
 - Gazell stack:
    - Fixed a bug with high current consumption in disabled state, related with TIMER issue 78.
    - Fixed a bug with reenabling Gazell stack after the SoftDevice activity.
 - Gazell Pairing Library:
    - Fixed a bug with unreserved flash memory region for the Host ID.
    - Fixed a bug with wrong initialization of database flash memory page on nRF52 chips.
 
** NFC **
 - Type 2 Tag Library:
    - Modified Dynamic Memory content of the Tag. Dynamic Lock Bytes use proper values now.
    - Updated CC1 byte setting (one of the Type 2 Tag Reserved bytes) according to the new NFC Forum Type 2 Tag Technical Specification v1.0.
 - Type 2 Tag HAL:
    - Handling of erroneous NFC-A data frames (with parity and CRC errors) has been improved.

** USB **
 - Fixed a bug in USB CDC ACM class where the APP_USBD_CDC_ACM_USER_EVT_PORT_OPEN event was not raised.
 - Fixed a bug in USB CDC ACM class where RX stopped working after the port was closed or the cable was detached.
 - Fixed a bug in USB MSC where it could not satisfy the number of required bytes by the host.
 - Fixed a bug in app_usbd.c where APP_USBD_EVT_DRV_RESUME event was raised after a reset instead of APP_USBD_EVT_DRV_RESET.
 - Fixed a bug in HID class where Remote Wake Up was not properly handled.
 - Fixed a bug in nrf_drv_usbd_transfer_out_drop() where it was clearing an isochronous endpoint.
 - Fixed a bug in app_usbd_core.c where transfer status was not checked during EP0 processing.
 - FTPAN-171 workaround has been implemented.
 - FTPAN-199 workaround has been implemented.
 - Fixed minor issues.
 

*** Known Issues
****************
 
** Missing feature on nRF52840 **
  - ANT protocol support is missing due to ANT SoftDevices not available for this device.
  - FreeRTOS
  - ESB
 
** BLE **
 - BLE LESC module should be treated as experimental, even though it has not been marked as such.
 - Eddystone example should be treated as experimental on nRF52840.
 
** BLE IOT **
 - Neighbor discovery module for lwIP requires the on-link flag in the
   router advertisement to be set in order to create a SLAAC address
   from the prefix. However, RFC 7668 (https://tools.ietf.org/html/rfc7668)
   requires this bit to be zero. Therefore, the nd6.c from lwIP source
   has been modified to relax this check.
 - There are some issues when using the IoT examples against Linux
   Kernel 4.12+ which causes the kernel to only work with one 6LoWPAN
   connection. If more than one kit is connected using 6LoWPAN, none of
   the nodes will be accessible.
 - Scheduler has been included in most IoT examples to avoid race
   conditions found when using the lwIP stack, more precisely the TCP
   examples.
   The issue was that the TCP client stopped working after about 15
   hours. However, when using mbed TLS, the use of scheduler is not
   possible.
   Therefore, the MQTT client examples might be affected by this issue.
 - The use of security, both with TLS and DTLS, should be treated as
   experimental.
 - MQTT examples cannot be used with commissioning on nRF52832. There is not enough
   RAM to accommodate both TLS and the commissioning service.
 - If enabled, RTT logs in IoT bootloader might not be printed before resetting.
 
** DFU/Bootloader **
 - Changing the backend for nrf_crypto in sdk_config.h alone is not sufficient
   because the relevant files are not included in the build and include paths.
   See the Migration Guide for a walkthrough of changing from the µECC to the
   Oberon backend.
 - ble_app_buttonless_dfu will silently hang during bootup if a compatible
   bootloader, i.e. the BLE bootloader, is not present.
 - SES will not detect whether the debug bootloader is too large, instead it will place the code in the MBR params page. To make SES detect this, add the following line in flash_placement.xml:
   <ProgramSection load="no" name=".reserved_flash_tail" start="$(FLASH_START)+$(FLASH_SIZE)" size="$(FLASH_PH_SIZE)-$(FLASH_START)-$(FLASH_SIZE)" />
   Place this line immediately after:
   <ProgramSection alignment="4" load="Yes" runin=".tdata_run" name=".tdata" />
   The production bootloader is not affected by this issue.
 - nrfutil version 3.5.0  has an optional argument to increase the time delay "--connect-delay <seconds>".
   It is recommended to set this value to 10 when Serial DFU (UART / USB) is performed for large images (SoftDevice + Application or SoftDevice + Bootloader + Application).
 - You may experience some instability with the µECC library in IAR due to faulty decoding of symbol information. Compile the µECC library without symbol information to fix these issues.

** Proprietary **
 - Gazell stack for all devices is working with sensitivity reduced by 3 dB due to the RADIO issues 102, 106, 107, and 143.
 
** NFC **
 - NFC Type 2 and Type 4 Tag HAL modules require using TIMER 4 on nRF52840 and nRF52832 chips.
 
** USBD **
 - For the sake of stability, the USBD driver blocks code execution during EasyDMA transfer.
 - Isochronous transfers must be processed as fast as possible, but using the event queue may postpone SOF processing too long if the CPU is busy. In such situations, isochronous transfers should be started inside a SOF interrupt. Configure APP_USBD_CONFIG_SOF_HANDLING_MODE as interrupt. The implementation of special SOF interrupt callbacks is subject of the future updates.
 
** Drivers and Libraries **
 - SAADC driver is not handling detection limits: high and low correctly if SAADC resolution is greater than 10 bits.
 - The following examples do not have Keil 4 support: nrf_cc310, nrf_cc310_bl, ifx_optiga_ecdsa_simple.

========================================================================

nRF5 SDK v14.2.0
------------------------
Release Date: Week 46, 2017

Highlights:

- Support for the new S112 SoftDevice v5.1.0.

The following toolchains/devices have been used for testing and
verification:
- ARM: MDK-ARM version 5.18a
- GCC: GCC ARM Embedded 4.9 2015q3
- IAR: IAR Workbench 7.80.4
- SES: SES 3.30
- Linux: Ubuntu 17.04, Kernel 4.10.0.
- Jlink: 6.20d

Supported SoftDevices:
- S112 v5.1.x
- S132 v5.0.x (for v5.1.x, see the note below)
- S140 v5.0.0-2.alpha
- S212 v5.0.x
- S332 v5.0.x

S132 compatibility:
The newly released S132 SoftDevice v5.1.0 is drop-in compatible with
S132 v5.0.0, which is included in this SDK release.
However, there are some limitations that you must be aware of when
replacing the included SoftDevice with the new one:
- In S132 v5.1.0, the SoftDevice RAM usage is reduced. Examples that are
  optimized on RAM usage return a warning that the application RAM start
  address can be lowered. The examples work as before but are not fully
  optimized on RAM usage.
- The test images in examples\dfu\secure_dfu_test_images are tightly
  connected with the precompiled HEX files located in
  examples\dfu\bootloader_secure_ble\hex. Therefore, they cannot be used
  in combination with the new SoftDevice.

Supported boards:
- PCA10040E (nRF52810 emulation on PCA10040)
- PCA10040
- PCA10056 (limited support; see the "Scope for the nRF52840 chip" section)
- Dynastream's D52DK1 (only for ANT examples)

For other devices and boards, see the SDK documentation, section "Using
the SDK with other boards".

*** Scope for the nRF52840 chip
********************************
All examples and libraries for the new chip must be treated as
experimental.
Some examples have not been ported to run on nRF52840. Check the
existing example projects to see which targets are supported.
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

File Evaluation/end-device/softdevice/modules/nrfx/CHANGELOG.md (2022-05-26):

# Changelog
All notable changes to this project are documented in this file.

## [1.8.4] - 2020-04-27
- Fixed an issue in the NFCT driver where the FIELDDETECTED event would be ignored and the FIELDLOST event would be processed twice. The driver now properly handles FIELDDETECTED and FIELDLOST events.

## [1.8.3] - 2020-03-20
### Added
- Added documentation pages for nRF52820.
- Added possibility to use the nRF52833 DK in development for nRF52820. LEDs and buttons in this DK use GPIOs that are not present in the actual nRF52820 device, so accesses to these need special handling in the GPIO HAL.

### Fixed
- Fixed assertions that check input pin selections in the legacy SAADC driver. Now the VDDHDIV5 setting is handled properly.
- Fixed the number of machine cycles per single delay loop for nRF52820 in the nrfx_coredep module.

## [1.8.2] - 2020-03-05
### Added
- Added support for nRF52820.
- Added new implementation of the SAADC driver. The new version is enabled when the NRFX_SAADC_API_V2 symbol is defined, otherwise the legacy one is used.
- Introduced the NRFX_TWIM_NO_SPURIOUS_STOP_CHECK flag in the TWIM driver.
- Added function for getting the configuration of shortcuts in the TWIM HAL.
- Implemented workaround for nRF9160 anomaly 23 in the UARTE driver.

### Changed
- Updated MDK to version 8.32.1.
- Improved the UARTE driver to consume less current after the driver uninitialization. Now all clocks are disabled properly.
- Improved the GPIOTE driver robustness by setting the LATCH functionality to be used by default.
- Improved handling of spurious STOP condition in the TWIM driver.
- Removed support for revision Engineering A of nRF52840 in the USBD driver.

### Fixed
- Fixed assertions that check write addresses in the NVMC driver. Now the UICR memory region is handled properly.
- Fixed an issue in the TWI driver that would make the driver stuck when a premature STOP condition was generated by a slave device. The driver now handles this situation properly and signals that a bus error occurred.
- Fixed the stopping procedure in the PWM driver. Previously in very specific circumstances the PWM output might be not stopped at all or might be immediately restarted.
- Fixed a race condition in the CLOCK driver when requested clock was stopped during ramp-up from high priority interrupt.
- Fixed assertions that check pin numbers in the GPIO HAL and GPIOTE driver. Now noncontiguous groups of available pin numbers are handled properly.

## [1.8.1] - 2019-10-21
### Added
- Added functions in the GPIOTE driver for getting task or event for the specified GPIO pin.

### Changed
- Updated MDK to version 8.27.1.
- Moved the nrfx_gppi helper from helpers/nrfx_gppi/ to helpers/.
- Changed the interrupt initialization in the GPIOTE driver, so that mapping of the GPIOTEx_IRQn enumeration values is no longer needed for nRF9160.

## [1.8.0] - 2019-08-27
### Added
- Added support for nRF52833.
- Added bus recovery feature in the TWI and TWIM drivers.
- Added the nrfx_gppi helper layer to facilitate developing generic code that can utilize PPI or DPPI, depending on which interface is available in a given SoC.

### Changed
- Updated MDK to version 8.27.0.

### Fixed
- Fixed an issue in the TWIM driver that would make the driver stuck when a premature STOP condition was generated by a slave device. The driver now handles this situation properly and signals that a bus error occurred.
- Fixed a frame timing bug in the NFCT driver. Previously, the timing of the SENS_RES response could be violated after the NFCT peripheral was put to the Sleep state with the SLP_REQ command.

## [1.7.2] - 2019-07-25
### Added
- Added functions in the DPPI, GPIOTE, PPI, RTC, and TIMER HALs for getting tasks and events specified by index.
- Added the possibility of suspending transfers in the TWI driver. This allows combining several transfers into one continuous TWI transaction.
- Added termination of transfers at deinitialization of the UARTE driver.
- Added buffer alignment checks in the QSPI driver.
- Introduced the NRFX_OFFSETOF macro that duplicates the functionality of the built-in offsetof() mechanism, but can be used without issues also with non-constant expressions.
- Added an alternative way of ending the DMA transfer loop in the USBD driver.
- Added the CTSTARTED and CTSTOPPED events to the CLOCK HAL.

### Changed
- Removed an assertion that prevented setting the data payload size of isochronous endpoints to zero, to fulfill requirements of the USB 2.0 specification, paragraph 5.6.3.
- Declared the tx_buffer_length field in the UART driver's control block as volatile to prevent issues in case of compilation with high optimization level.

### Fixed
- Fixed an incorrect conversion of frequency values in the RADIO HAL.
- Fixed an incorrectly enabled interrupt in the QSPI driver.
- Corrected the LFCLK source selection values in the template configuration file for nRF9160.
- Fixed support for external LFCLK sources for nRF52811.

## [1.7.1] - 2019-04-08
### Added
- Added functions in the NVMC driver for getting the flash page size, the count of pages and the total flash size.

### Fixed
- Fixed handling of short unaligned write requests (1 or 2 bytes in length) in the nrfx_nvmc_bytes_write() function.

## [1.7.0] - 2019-03-29
### Added
- Added drivers for NVMC and TEMP.
- Added HALs: AAR and FICR.
- Added support for the custom instruction long frame mode in the QSPI driver.

### Changed
- Reworked HAL for NVMC. Now it can be used for all SoCs supported by nrfx.
- Reworked HAL for TEMP.
- Improved documentation. Now it is more precise and can be generated without warnings with newer versions of doxygen.
- Improved the UARTE driver to consume less current after the TX operation. Now at the end of the transmission the transmitter is turned off by the STOPTX task.
- Improved C++ support in drivers. Now fields in structures are filled up in the correct order.
- Changed to size_t the type used for holding the amount of data in the TWIS driver.

### Fixed
- Fixed a race condition in the USBD driver. It could occur when an IN transfer was interrupted by an OUT transaction, which in turn was interrupted by a process with a higher priority.

## [1.6.2] - 2019-02-12
### Added
- Added the possibility to use the macro NRFX_COREDEP_DELAY_US_LOOP_CYCLES to specify the number of cycles consumed by one iteration of the internal loop in the function nrfx_coredep_delay_us().

### Changed
- Updated MDK to version 8.24.1.

## [1.6.1] - 2019-01-29
### Fixed
- Fixed an issue in the NFCT driver that caused a performance loss on nRF52832. The interrupt configuration is now properly restored after the NRFX_NFCT_EVT_FIELD_LOST event.

## [1.6.0] - 2019-01-18
### Added
- Added support for nRF52811.
- Added support for the legacy peripherals SPI, TWI, and UART in nRF52810.
- Added support for SAMPLERATE in nrf_saadc.h.
- Added clearing of the STOPPED event in the nrfx_saadc_init() function to prevent driver deadlock in some cases.
- Added HALs: BPROT, MPU, MWU.
- Added function for reading the pin input buffer configuration in the GPIO HAL.
- Implemented workaround for nRF9160 anomaly 1 in the I2S driver.

### Changed
- Improved handling of hardware anomalies in the USBD driver.
- Updated MDK to version 8.23.1.

### Fixed
- Fixed the condition in NRFX_WAIT_FOR in the nrfx_saadc_abort() function. The macro now correctly waits for a stop of the driver.
- Fixed the pending interrupt clearing in NVIC in the nrfx_usbd_stop() function. The driver now correctly handles power management.
- Fixed the case when nrfx_uarte_tx_in_progress() function would return an incorrect value. The driver now correctly updates the tx_buffer_length variable internally.

## [1.5.0] - 2018-12-12
### Added
- Added support for nRF9160.
- Added allocator for DPPI.
- Added HALs: DPPI, KMU, REGULATORS, SPU, VMC.
- Added support for DPPI subscription and publishing in HALs related to nRF9160.
- Added support for instances 2 and 3 in SPIS, TWIM, TWIS, and UARTE drivers.

### Changed
- Updated MDK to version 8.21.1.

### Fixed
- Corrected NRFX_I2S_CONFIG_RATIO value in nrfx_config.h. It now correctly uses supported value.

## [1.4.0] - 2018-11-30
### Added
- Added the nrfx_is_word_aligned() function for checking whether an address is word-aligned.
- Added HAL for ACL.
- Added functions for disabling and re-enabling interrupts in the SWI driver.
- Added possibility to completely remove interrupt handling from the WDT driver.

### Changed
- Updated the documentation for the nrfx_uarte_rx() function. It now correctly reflects the actual behavior of the function.

### Fixed
- Corrected the type of the nrfx_uarte_xfer_evt_t structure field that holds the amount of transferred bytes.
- Corrected the way of disabling interrupts in the NFCT driver when moving the peripheral to the disabled state.
- Fixed a typo in the name of the bmRequest field in the nrfx_usbd_setup_t structure. The new correct name is bRequest.
- Fixed the nrfx_ppi_channel_fork_assign() function. It now accepts also pre-programmed channels.
- Fixed handling of long custom instruction responses in the QSPI driver.
- Fixed a bug affecting the conversion of time to ticks in the TIMER HAL.

## [1.3.1] - 2018-09-28
### Fixed
- Corrected the type of nrfx_usbd_ep_status_get() return value.
- Corrected calls to undefined macros in NFCT and USBD drivers.

## [1.3.0] - 2018-09-21
### Added
- Added HAL and driver for NFCT.
- Added driver for USBD.
- Added function for setting the burst mode in the SAADC HAL.
- Added the NRFX_ARRAY_SIZE macro.

### Changed
- Moved the implementation of nrfx_power_clock_irq_handler() to nrfx_power.c, removed nrfx_power_clock.c.

### Fixed
- Replaced ARRAY_SIZE macro calls with NRFX_ARRAY_SIZE ones.

## [1.2.0] - 2018-09-06
### Added
- Added function for checking if a specific channel is enabled in the GPIOTE HAL.
- Added support for using the QDEC driver without LED.
- Added functions for modifying only the event endpoint or only the task endpoint in the PPI HAL.
- Added function for reading the pin pull configuration in the GPIO HAL.

### Changed
- Corrected ISOSPLIT enumerator names in the USBD HAL.

### Fixed
- Fixed a double buffering bug that occurred in the UARTE driver after the RX abort.
- Fixed the TXRX transfers in the TWIM driver. They can now be started after transfers that are not ended with the stop condition.

## [1.1.0] - 2018-06-15
### Added
- Implemented workaround for nRF52832 and nRF52840 anomaly 194 in the I2S driver.
- Implemented workaround for nRF52840 anomaly 195 in the SPIM driver.
- Added HALs for CCM, ECB, and RADIO.
- Extended HALs for GPIO, PPI, SAADC, and USBD.
- Added support for external LFCLK sources.

### Changed
- Corrected handling of transfer lengths in the TWI driver.
- Updated MDK to version 8.17.0.

### Fixed
- Fixed logging in the PPI driver.
- Fixed SPIM interrupt definition for nRF52810.
- Fixed Slave Select configuration in the SPIM driver.
- Corrected default settings for NRF_SPIM3.
- Fixed a typo in the UARTE TXDRDY event definition.
- Corrected the TIMEOUT event clearing in the WDT interrupt handler.

## [1.0.0] - 2018-03-21
### Added
- Added the NRFX_WAIT_FOR macro to improve the time-out functionality in QSPI and SAADC drivers.
- Added glue layer macros for checking and modifying the pending status of interrupts.
- Added new enumeration values for interrupts and events in the UARTE HAL.
- Implemented workarounds for nRF52 anomalies 192 and 201 in the CLOCK driver.
- Implemented workaround for nRF52840 anomaly 122 in the QSPI driver.
- Implemented workaround for nRF52840 anomaly 198 in the SPIM driver.

### Changed
- Updated MDK to 8.16.0.
- Extended input pin configuration in the GPIOTE driver.
- Unified the way of checking if a required event handler was provided. Now, all drivers do it with assertions.
- Changed the RNG bias correction configuration option to be enabled by default.
- Refactored the ADC driver and HAL.
- Corrected assertions in the TIMER driver to make it usable in debug version with PPI.
- Improved buffer handling in the I2S driver. The API of the driver has been slightly modified.
- Enhanced SPIS driver API: added the "p_context" parameter, allowed NULL pointers for zero-length buffers.

### Fixed
- Fixed result value casting in the TEMP HAL.
- Fixed types of conversion result and buffer size in the ADC HAL and driver.
- Fixed time-out in the SAADC driver in abort function.

## [0.8.0] - 2017-12-20
### Added
- Added XIP support in the QSPI driver.
- Implemented Errata 132 in the CLOCK driver.
- Added function for checking if a TIMER instance is enabled.
- Added extended SPIM support.

### Changed
- Updated MDK to 8.15.0. Introduced Segger Embedded Studio startup files.
- Updated drivers: COMP, PWM, QDEC, SAADC, SPIS, TIMER, TWI, TWIS.
- Changed the type used for transfer lengths to 'size_t' in drivers: SPI, SPIM, SPIS, TWI, TWIM, TWIS, UART, UARTE. Introduced checking of EasyDMA transfers limits.
- Updated HALs: COMP, NVMC, UART, UARTE, USBD.
- Updated template files and documentation of configuration options.

### Fixed
- Fixed TWI and TWIM drivers so that they now support GPIOs from all ports.
- Fixed definitions related to compare channels in the TIMER HAL.

### Removed
- Removed the possibility of passing NULL instead of configuration to get default settings during drivers initialization.
- Removed support for UART1 and PRS box #5.

## [0.7.0] - 2017-10-20
### Added
- This CHANGELOG.md file.
- README.md file with simple description and explanations.
- HAL for: ADC, CLOCK, COMP, ECB, EGU, GPIO, GPIOTE, I2S, LPCOMP, NVMC, PDM, POWER, PPI, PWM, QDEC, QSPI, RNG, RTC, SAADC, SPI, SPIM, SPIS, ARM(R) SysTick, TEMP, TIMER, TWI, TWIM, TWIS, UART, UARTE, USBD, WDT.
- Drivers for: ADC, CLOCK, COMP, GPIOTE, I2S, LPCOMP, PDM, POWER, PWM, QDEC, QSPI, RNG, RTC, SAADC, SPI, SPIM, SPIS, ARM(R) SysTick, TIMER, TWI, TWIM, TWIS, UART, UARTE, WDT.
- Allocators for: PPI, SWI/EGU.
- MDK in version 8.14.0.
- Offline documentation for every added driver and simple integration description.
- Template integration files.

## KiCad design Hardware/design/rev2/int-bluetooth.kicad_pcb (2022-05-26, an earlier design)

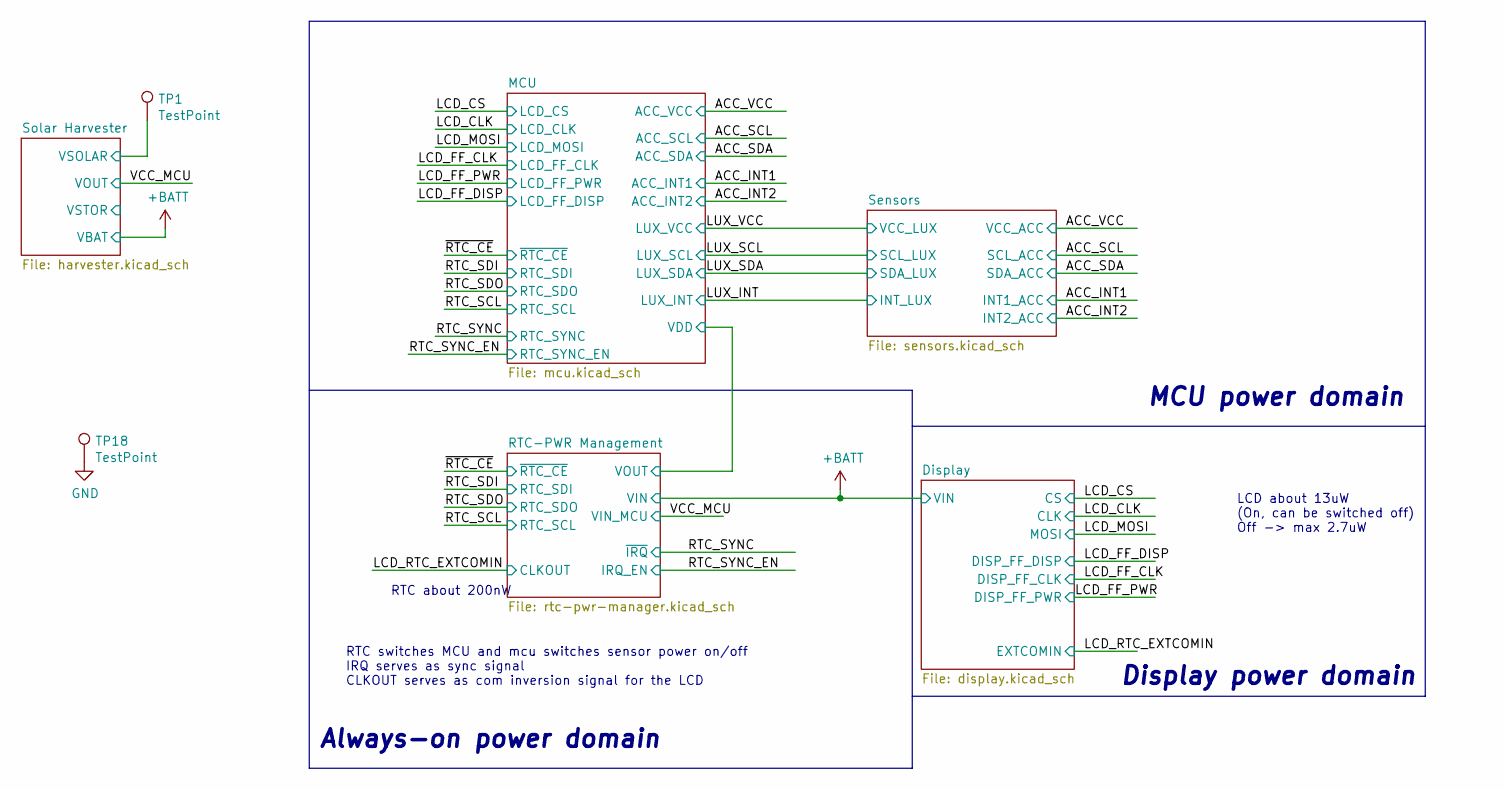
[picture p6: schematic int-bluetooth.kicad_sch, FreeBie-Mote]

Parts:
TP1, TP18: TestPoint; SMOX_PCB_TESTPOINT; MPN SMOX/060/B1/HT

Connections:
/Solar Harvester/VSOLAR: TP1.1; also elsewhere on the board
GND: TP18.1; also elsewhere on the board

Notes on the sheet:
Display power domain
LCD about 13uW (On, can be switched off) Off -> max 2.7uW
RTC about 200nW
Always-on power domain
RTC switches MCU and mcu switches sensor power on/off IRQ serves as sync signal CLKOUT serves as com inversion signal for the LCD
MCU power domain

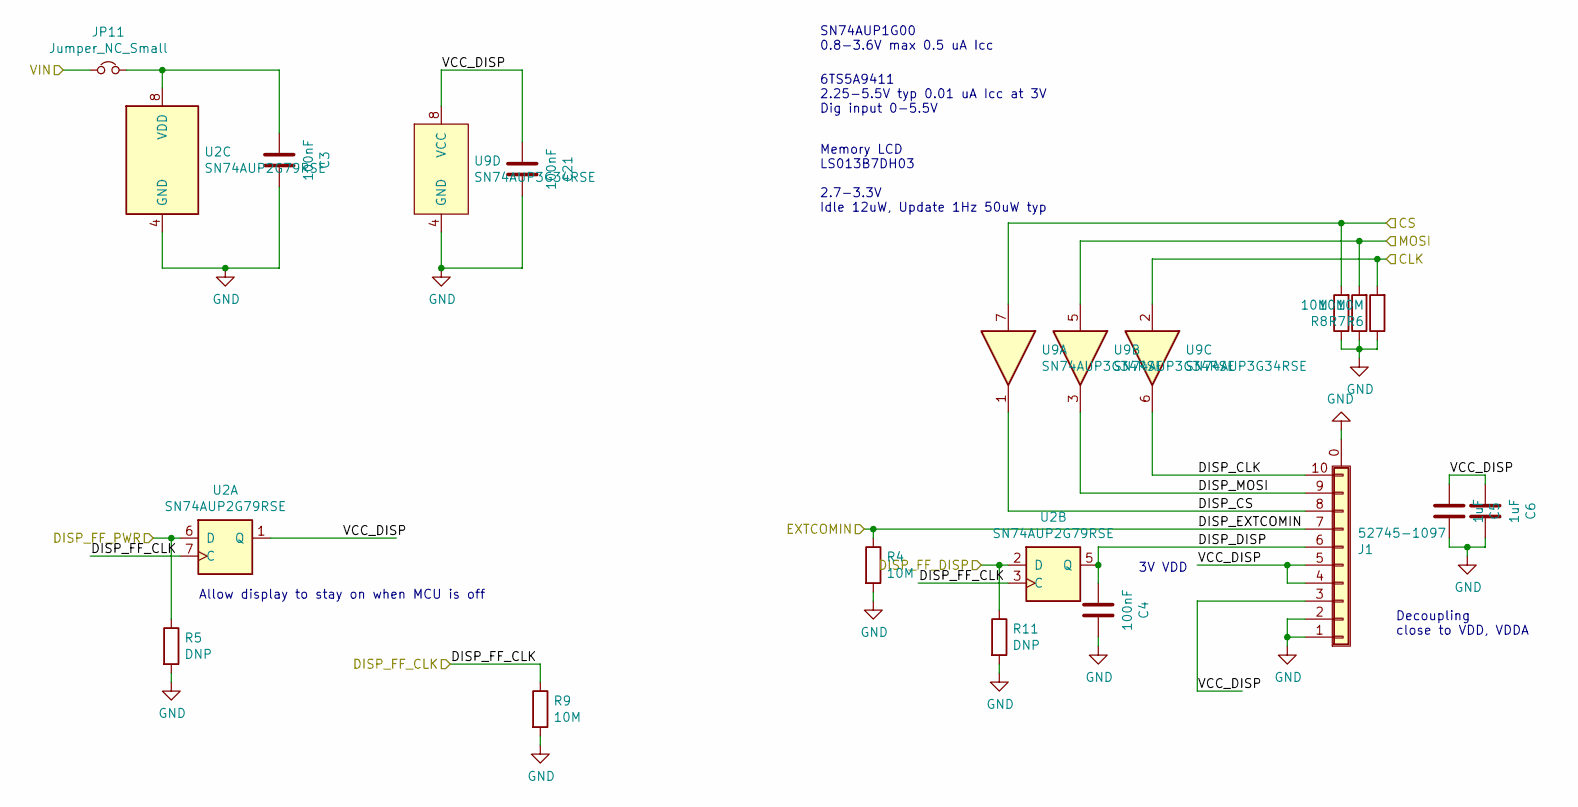
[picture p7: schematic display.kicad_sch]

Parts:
C3, C4, C21: 100nF; C_0402_1005Metric; MPN GRM155R71C104KA88J
C5, C6: 1uF; C_0402_1005Metric; MPN 0402ZD105KAT2A
J1: 52745-1097; FPC_10_TOP; MPN 52745-1097
JP11: Jumper_NC_Small; SolderJumper-small-nc
R4, R6, R7, R8, R9: 10M; R_0402_1005Metric; MPN RC0402FR-0710ML
R5, R11: DNP; R_0402_1005Metric
U2: SN74AUP2G79RSE; Texas_RSE_8_UQFN; MPN SN74AUP2G79RSE
U9: SN74AUP3G34RSE; Texas_RSE_8_UQFN; MPN SN74AUP3G34RSE

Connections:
+BATT: JP11.1; also elsewhere on the board
/Display/DISP_CLK: J1.10, U9.6
/Display/DISP_CS: J1.8, U9.1
/Display/DISP_DISP: C4.1, J1.6, U2.5 (Q)
/Display/DISP_MOSI: J1.9, U9.3
/Display/VCC_DISP: C5.1, C6.1, C21.1, J1.3, J1.4, J1.5, U2.1 (Q), U9.8 (VCC)
/LCD_CLK: R6.2, U9.2; also elsewhere on the board
/LCD_CS: R8.2, U9.7; also elsewhere on the board
/LCD_FF_CLK: R9.1, U2.3 (C), U2.7 (C); also elsewhere on the board
/LCD_FF_DISP: R11.1, U2.2 (D); also elsewhere on the board
/LCD_FF_PWR: R5.1, U2.6 (D); also elsewhere on the board
/LCD_MOSI: R7.2, U9.5; also elsewhere on the board
/LCD_RTC_EXTCOMIN: J1.7, R4.1; also elsewhere on the board
GND: C3.2, C4.2, C5.2, C6.2, C21.2, J1.0 (Shield), J1.1, J1.2, R4.2, R5.2, R6.1, R7.1, R8.1, R9.2, R11.2, U2.4 (GND), U9.4 (GND); also elsewhere on the board
unnamed: C3.1, JP11.2, U2.8 (VDD)

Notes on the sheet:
Memory LCD LS013B7DH03 2.7-3.3V Idle 12uW, Update 1Hz 50uW typ
SN74AUP1G00 0.8-3.6V max 0.5 uA Icc
Allow display to stay on when MCU is off
Decoupling close to VDD, VDDA
3V VDD
6TS5A9411 2.25-5.5V typ 0.01 uA Icc at 3V Dig input 0-5.5V

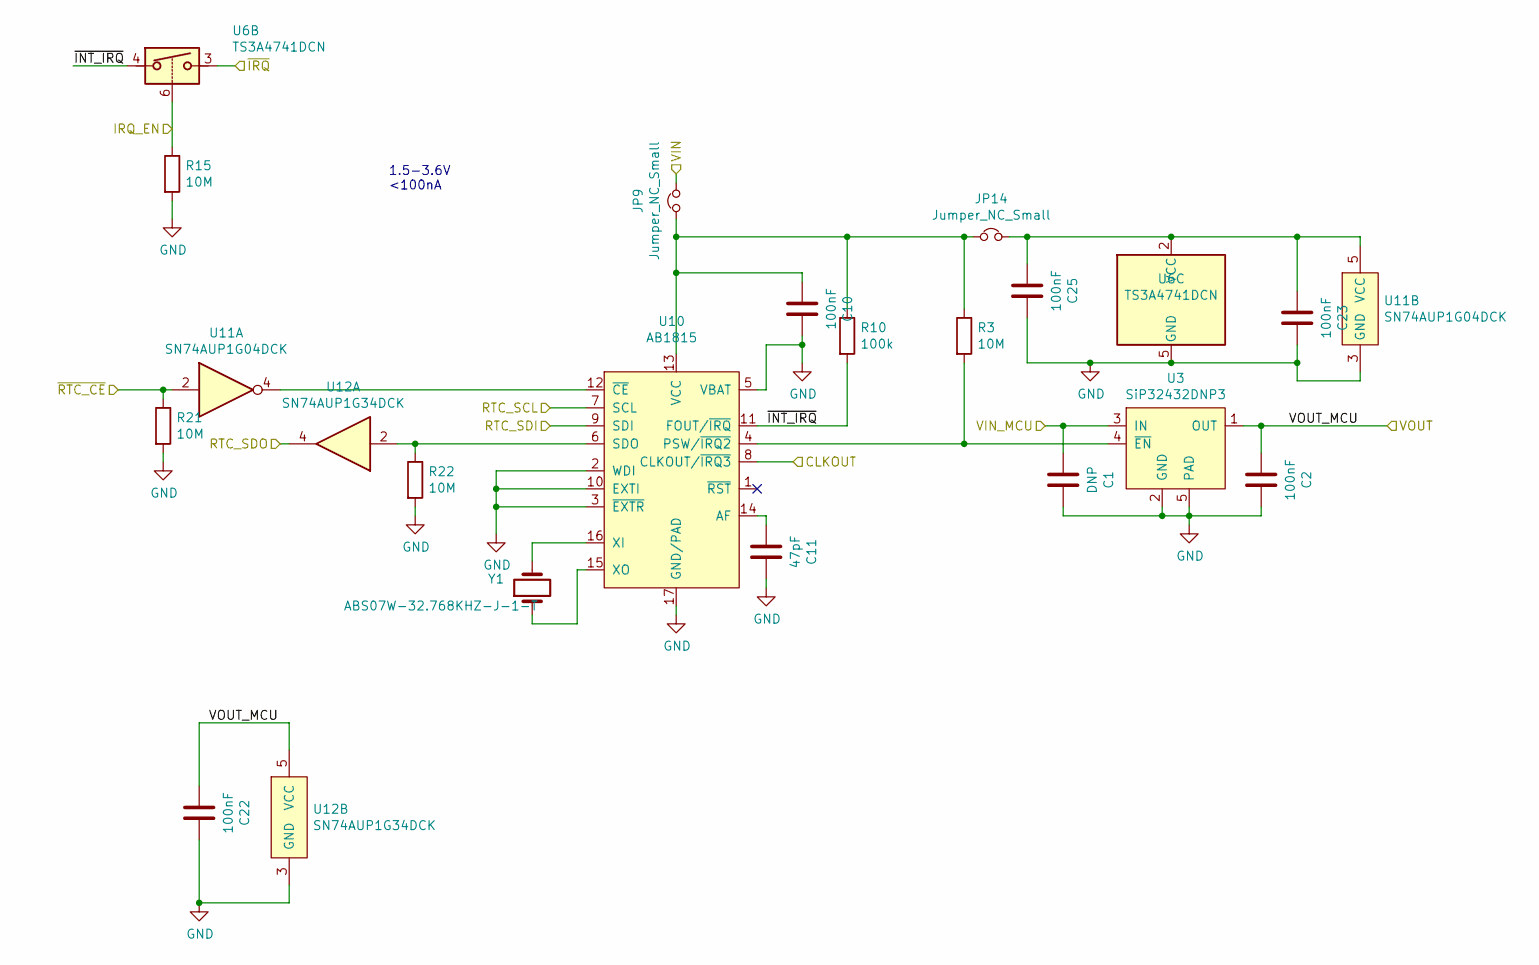
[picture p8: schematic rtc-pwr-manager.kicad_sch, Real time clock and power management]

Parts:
C1: DNP; C_0402_1005Metric
C2, C10, C22, C23, C25: 100nF; C_0402_1005Metric; MPN GRM155R71C104KA88J
C11: 47pF; C_0402_1005Metric; MPN GJM1555C1H470FB01D
JP9, JP14: Jumper_NC_Small; SolderJumper-small-nc
R3, R15, R21, R22: 10M; R_0402_1005Metric; MPN RC0402FR-0710ML
R10: 100k; R_0402_1005Metric; MPN RC0402FR-07100KL
U3: SiP32432DNP3; DFN-4-1EP_1.6x1.2mm_P0.5mm_EP; MPN SIP32432DNP3-T1GE4
U6: TS3A4741DCN; SOT-23-8; MPN TS3A4741DCN
U10: AB1815; QFN-16-1EP_3x3mm_P0.5mm_EP1.75x1.75mm_ThermalVias; MPN AM1815
U11: SN74AUP1G04DCK; Texas_R-PDSO-G5; MPN SN74AUP1G04DCK
U12: SN74AUP1G34DCK; Texas_R-PDSO-G5; MPN SN74AUP1G34DCK
Y1: ABS07W-32.768KHZ-J-1-T; Crystal_SMD_3215-2Pin_3.2x1.5mm; MPN ABS07W-32.768KHZ-J-1-T

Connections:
+BATT: JP9.2; also elsewhere on the board
/LCD_RTC_EXTCOMIN: U10.8 (CLKOUT/~IRQ3); also elsewhere on the board
/RTC-PWR Management/VOUT_MCU: C2.1, C22.1, U3.1 (OUT), U12.5 (VCC); also elsewhere on the board
/RTC-PWR Management/~INT_IRQ: R10.2, U6.4, U10.11 (FOUT/~IRQ)
/RTC_SCL: U10.7 (SCL); also elsewhere on the board
/RTC_SDI: U10.9 (SDI); also elsewhere on the board
/RTC_SDO: U12.4; also elsewhere on the board
/RTC_SYNC: U6.3; also elsewhere on the board
/RTC_SYNC_EN: R15.1, U6.6; also elsewhere on the board
/VCC_MCU: C1.1, U3.3 (IN); also elsewhere on the board
/~RTC_CE: R21.1, U11.2; also elsewhere on the board
GND: C1.2, C2.2, C10.2, C11.2, C22.2, C23.2, C25.2, R15.2, R21.2, R22.2, U3.2 (GND), U3.5 (PAD), U6.5 (GND), U10.2 (WDI), U10.3 (~EXTR), U10.5 (VBAT), U10.10 (EXTI), U10.17 (GND/PAD), U11.3 (GND), U12.3 (GND); also elsewhere on the board
unnamed: C10.1, JP9.1, JP14.1, R3.1, R10.1, U10.13 (VCC)
unnamed: C11.1, U10.14 (AF)
unnamed: C23.1, C25.1, JP14.2, U6.2 (VCC), U11.5 (VCC)
unnamed: R3.2, U3.4 (~EN), U10.4 (PSW/~IRQ2)
unnamed: R22.1, U10.6 (SDO), U12.2
unnamed: U10.12 (~CE), U11.4
unnamed: U10.15 (XO), Y1.1
unnamed: U10.16 (XI), Y1.2

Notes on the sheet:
1.5-3.6V <100nA

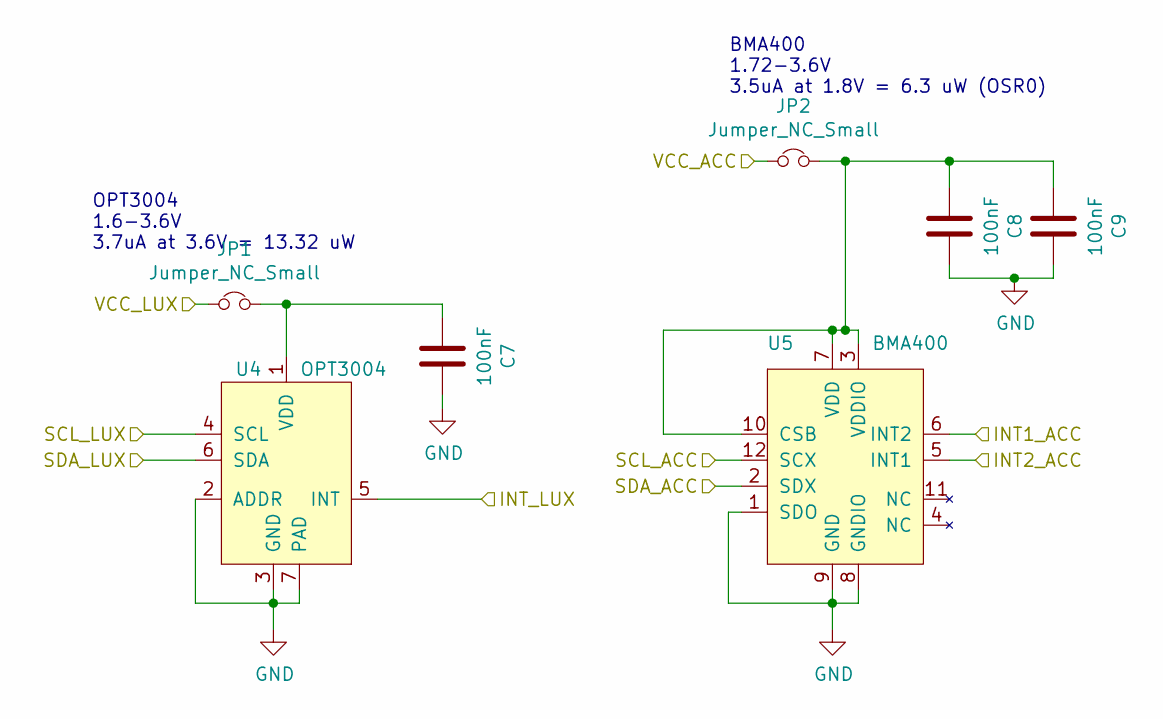
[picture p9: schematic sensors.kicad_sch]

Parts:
C7, C8, C9: 100nF; C_0402_1005Metric; MPN GRM155R71C104KA88J
JP1, JP2: Jumper_NC_Small; SolderJumper-small-nc
U4: OPT3004; USON6-OPT3004; MPN OPT3004DNPR
U5: BMA400; MPN BMA400

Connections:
/ACC_INT1: U5.6 (INT2); also elsewhere on the board
/ACC_INT2: U5.5 (INT1); also elsewhere on the board
/ACC_SCL: U5.12 (SCX); also elsewhere on the board
/ACC_SDA: U5.2 (SDX); also elsewhere on the board
/ACC_VCC: JP2.1; also elsewhere on the board
/LUX_INT: U4.5 (INT); also elsewhere on the board
/LUX_SCL: U4.4 (SCL); also elsewhere on the board
/LUX_SDA: U4.6 (SDA); also elsewhere on the board
/LUX_VCC: JP1.1; also elsewhere on the board
GND: C7.2, C8.2, C9.2, U4.2 (ADDR), U4.3 (GND), U4.7 (PAD), U5.1 (SDO), U5.8 (GNDIO), U5.9 (GND); also elsewhere on the board
unnamed: C7.1, JP1.2, U4.1 (VDD)
unnamed: C8.1, C9.1, JP2.2, U5.3 (VDDIO), U5.7 (VDD), U5.10 (CSB)

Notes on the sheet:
OPT3004 1.6-3.6V 3.7uA at 3.6V = 13.32 uW
BMA400 1.72-3.6V 3.5uA at 1.8V = 6.3 uW (OSR0)

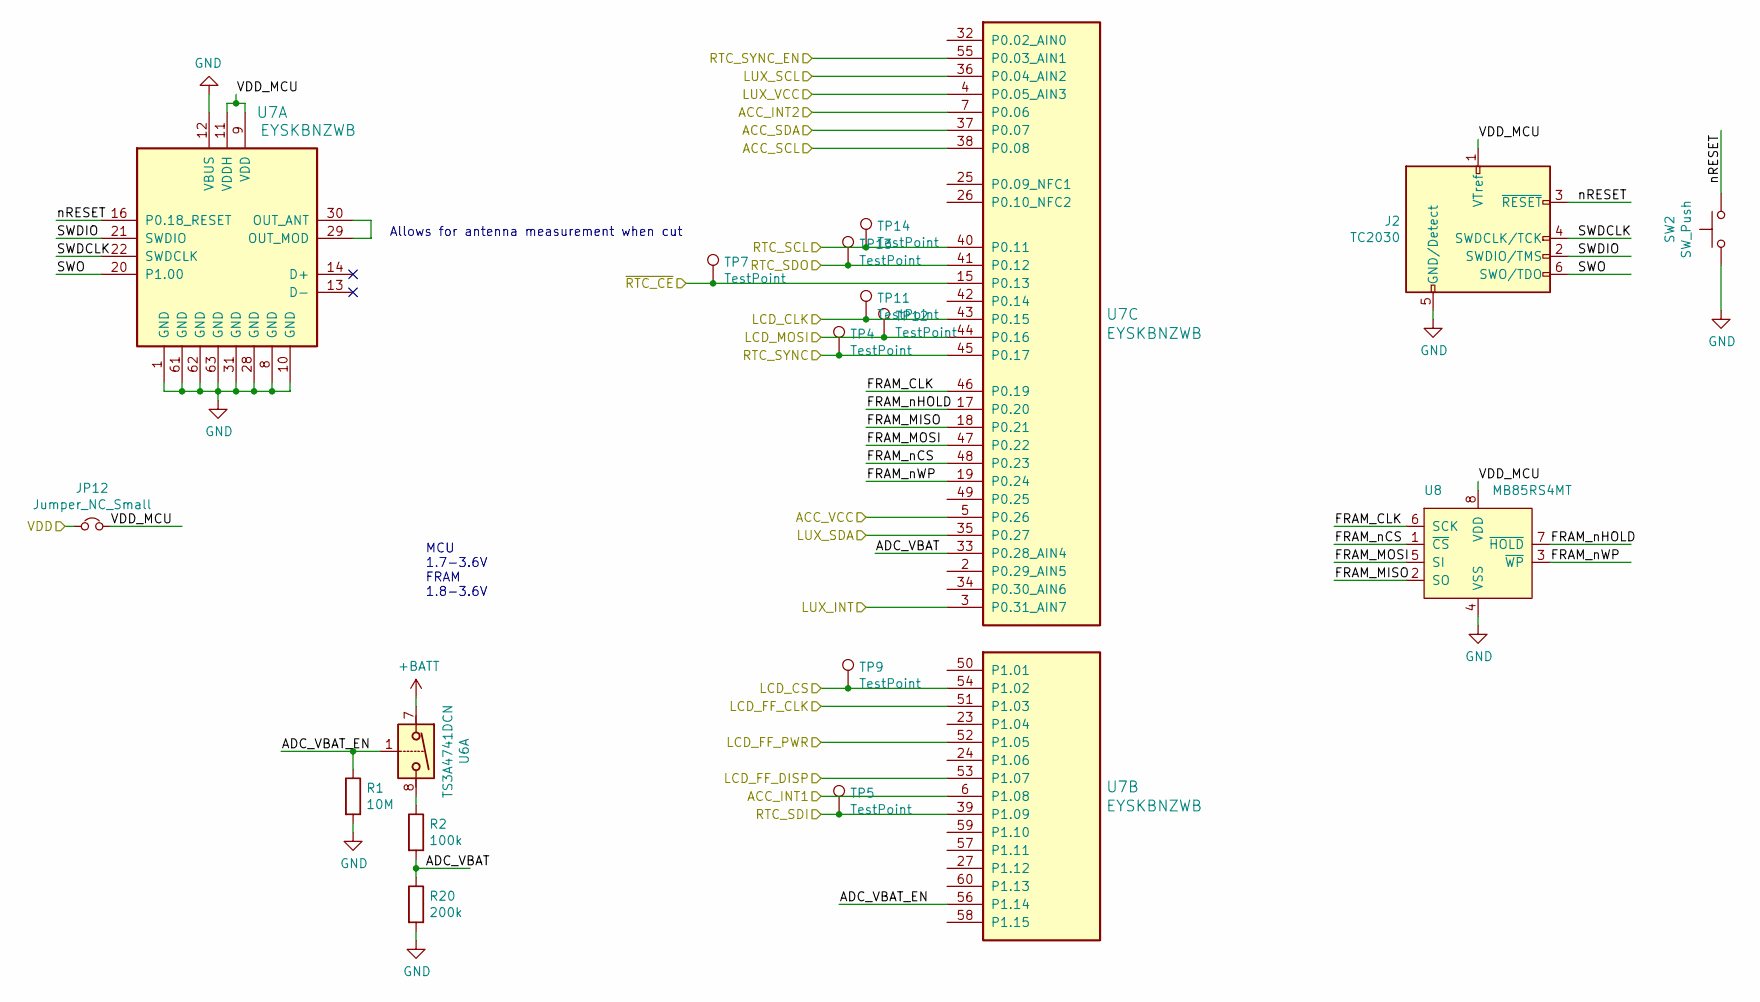
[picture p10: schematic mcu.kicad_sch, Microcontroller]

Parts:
J2: TC2030; Tag-Connect_TC2030-IDC-NL_2x03_P1.27mm_Vertical
JP12: Jumper_NC_Small; SolderJumper-small-nc
R1: 10M; R_0402_1005Metric; MPN RC0402FR-0710ML
R2: 100k; R_0402_1005Metric; MPN RC0402FR-07100KL
R20: 200k; R_0402_1005Metric; MPN RC0402FR-07200KL
SW2: SW_Push; SW_SPST_B3U-1000P; MPN B3U-1000P
TP4, TP5, TP7, TP9, TP11, TP12, TP13, TP14: TestPoint; SMOX_PCB_TESTPOINT; MPN SMOX/060/B1/HT
U6: TS3A4741DCN; SOT-23-8; MPN TS3A4741DCN
U7: EYSKBNZWB; MPN EYSKBNZWB
U8: MB85RS4MT; SO-8_5.3x6.2mm_P1.27mm; MPN MB85RS4MT

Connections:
+BATT: U6.7; also elsewhere on the board
/ACC_INT1: U7.6 (P1.08); also elsewhere on the board
/ACC_INT2: U7.7 (P0.06); also elsewhere on the board
/ACC_SCL: U7.38 (P0.08); also elsewhere on the board
/ACC_SDA: U7.37 (P0.07); also elsewhere on the board
/ACC_VCC: U7.5 (P0.26); also elsewhere on the board
/LCD_CLK: TP11.1, U7.43 (P0.15); also elsewhere on the board
/LCD_CS: TP9.1, U7.54 (P1.02); also elsewhere on the board
/LCD_FF_CLK: U7.51 (P1.03); also elsewhere on the board
/LCD_FF_DISP: U7.53 (P1.07); also elsewhere on the board
/LCD_FF_PWR: U7.52 (P1.05); also elsewhere on the board
/LCD_MOSI: TP12.1, U7.44 (P0.16); also elsewhere on the board
/LUX_INT: U7.3 (P0.31_AIN7); also elsewhere on the board
/LUX_SCL: U7.36 (P0.04_AIN2); also elsewhere on the board
/LUX_SDA: U7.35 (P0.27); also elsewhere on the board
/LUX_VCC: U7.4 (P0.05_AIN3); also elsewhere on the board
/MCU/ADC_VBAT: R2.2, R20.1, U7.33 (P0.28_AIN4)
/MCU/ADC_VBAT_EN: R1.1, U6.1, U7.56 (P1.14)
/MCU/FRAM_CLK: U7.46 (P0.19), U8.6 (SCK)
/MCU/FRAM_MISO: U7.18 (P0.21), U8.2 (SO)
/MCU/FRAM_MOSI: U7.47 (P0.22), U8.5 (SI)
/MCU/FRAM_nCS: U7.48 (P0.23), U8.1 (~CS)
/MCU/FRAM_nHOLD: U7.17 (P0.20), U8.7 (~HOLD)
/MCU/FRAM_nWP: U7.19 (P0.24), U8.3 (~WP)
/MCU/SWDCLK: J2.4 (SWDCLK/TCK), U7.22 (SWDCLK)
/MCU/SWDIO: J2.2 (SWDIO/TMS), U7.21 (SWDIO)
/MCU/SWO: J2.6 (SWO/TDO), U7.20 (P1.00)
/MCU/VDD_MCU: J2.1 (VTref), JP12.2, U7.9 (VDD), U7.11 (VDDH), U8.8 (VDD)
/MCU/nRESET: J2.3 (~RESET), SW2.2, U7.16 (P0.18_RESET)
/RTC-PWR Management/VOUT_MCU: JP12.1; also elsewhere on the board
/RTC_SCL: TP14.1, U7.40 (P0.11); also elsewhere on the board
/RTC_SDI: TP5.1, U7.39 (P1.09); also elsewhere on the board
/RTC_SDO: TP13.1, U7.41 (P0.12); also elsewhere on the board
/RTC_SYNC: TP4.1, U7.45 (P0.17); also elsewhere on the board
/RTC_SYNC_EN: U7.55 (P0.03_AIN1); also elsewhere on the board
/~RTC_CE: TP7.1, U7.15 (P0.13); also elsewhere on the board
GND: J2.5 (GND/Detect), R1.2, R20.2, SW2.1, U7.1 (GND), U7.8 (GND), U7.10 (GND), U7.12 (VBUS), U7.28 (GND), U7.31 (GND), U7.61 (GND), U7.62 (GND), U7.63 (GND), U8.4 (VSS); also elsewhere on the board
unnamed: R2.1, U6.8
unnamed: U7.29 (OUT_MOD), U7.30 (OUT_ANT)

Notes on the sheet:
MCU 1.7-3.6V FRAM 1.8-3.6V
Allows for antenna measurement when cut

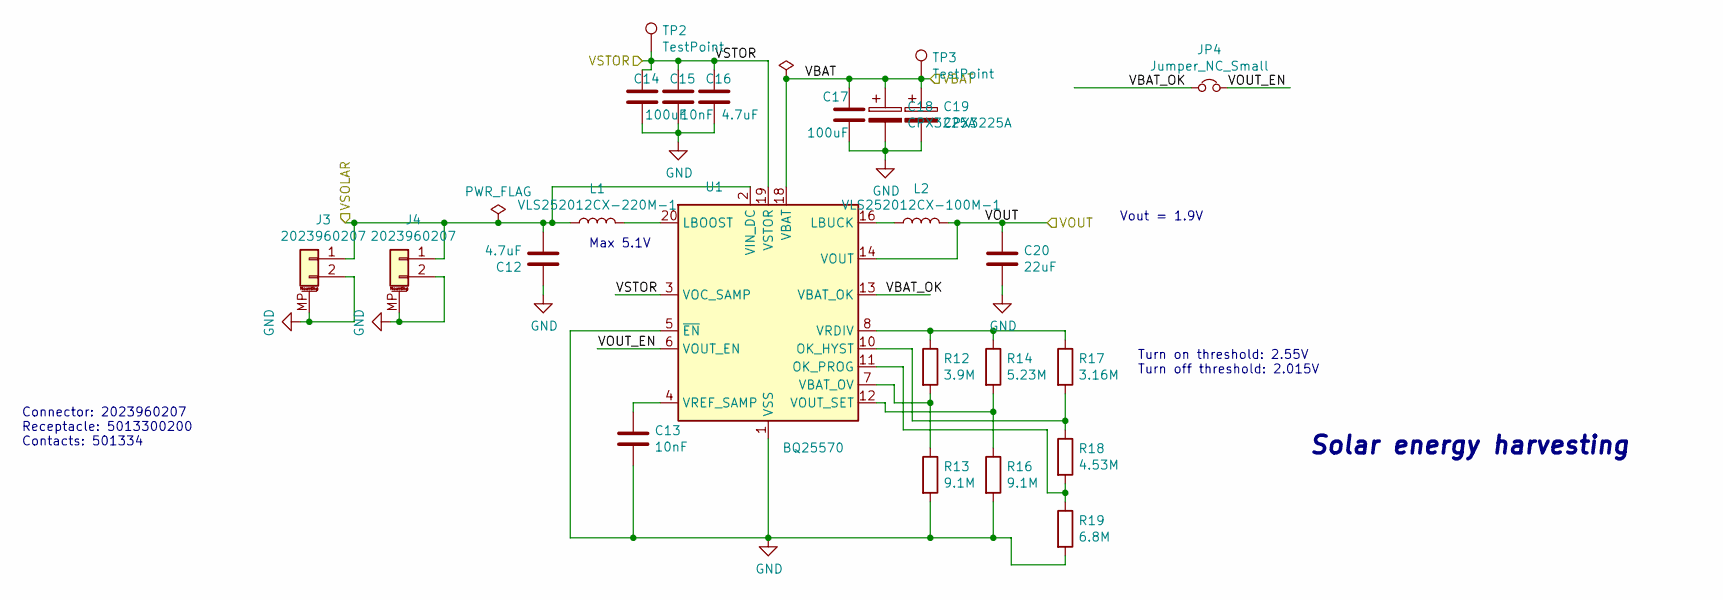
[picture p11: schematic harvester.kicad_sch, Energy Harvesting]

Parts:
C12, C16: 4.7uF; C_0402_1005Metric; MPN LMK105BBJ475MVLF
C13, C15: 10nF; C_0402_1005Metric; MPN GCM155R71H103KA55D
C14, C17: 100uF; C_1210_3225Metric
C18, C19: CPX3225A; MPN CPX3225A
C20: 22uF; C_0603_1608Metric; MPN GRM188R60J226MEA0D
J3, J4: 2023960207; Molex_Pico-Clasp_202396-0207_1x02-1MP_P1.00mm_Horizontal; MPN 202396-0207
JP4: Jumper_NC_Small; SolderJumper-small-nc
L1: VLS252012CX-220M-1; VLS252012CX-1; MPN VLS252012CX-220M-1
L2: VLS252012CX-100M-1; VLS252012CX-1; MPN VLS252012CX-100M-1
R12: 3.9M; R_0402_1005Metric; MPN MCHVR02FTFY3904
R13, R16: 9.1M; R_0402_1005Metric; MPN CRCW04029M10FKED
R14: 5.23M; R_0402_1005Metric; MPN CRCW04025M23FKED
R17: 3.16M; R_0402_1005Metric; MPN CRCW04023M16FKED
R18: 4.53M; R_0402_1005Metric; MPN RMCF0402FT4M53
R19: 6.8M; R_0402_1005Metric; MPN MCHVR02FTFY6804
TP2, TP3: TestPoint; SMOX_PCB_TESTPOINT; MPN SMOX/060/B1/HT
U1: BQ25570; QFN-20-1EP_3.5x3.5mm_P0.5mm_EP2x2mm; MPN BQ25570RGR

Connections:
+BATT: C17.2, C18.1, C19.1, TP3.1, U1.18 (VBAT); also elsewhere on the board
/Solar Harvester/VBAT_OK: JP4.1, U1.13 (VBAT_OK)
/Solar Harvester/VOUT_EN: JP4.2, U1.6 (VOUT_EN)
/Solar Harvester/VSOLAR: C12.2, J3.1, J4.1, L1.1, U1.2 (VIN_DC); also elsewhere on the board
/Solar Harvester/VSTOR: C14.2, C15.2, C16.2, TP2.1, U1.3 (VOC_SAMP), U1.19 (VSTOR)
/VCC_MCU: C20.1, L2.2, U1.14 (VOUT); also elsewhere on the board
GND: C12.1, C13.2, C14.1, C15.1, C16.1, C17.1, C18.2, C19.2, C20.2, J3.2, J3.MP (MountPin), J4.2, J4.MP (MountPin), R13.2, R16.2, R19.2, U1.1 (VSS), U1.5 (~EN), U1.9 (VSS), U1.15 (VSS), U1.17 (VSS), U1.21 (VSS); also elsewhere on the board
unnamed: C13.1, U1.4 (VREF_SAMP)
unnamed: L1.2, U1.20 (LBOOST)
unnamed: L2.1, U1.16 (LBUCK)
unnamed: R12.1, R14.1, R17.1, U1.8 (VRDIV)
unnamed: R12.2, R13.1, U1.7 (VBAT_OV)
unnamed: R14.2, R16.1, U1.12 (VOUT_SET)
unnamed: R17.2, R18.1, U1.10 (OK_HYST)
unnamed: R18.2, R19.1, U1.11 (OK_PROG)

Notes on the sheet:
Max 5.1V
Solar energy harvesting
Vout = 1.9V
Turn on threshold: 2.55V Turn off threshold: 2.015V
Connector: 2023960207 Receptacle: 5013300200 Contacts: 501334

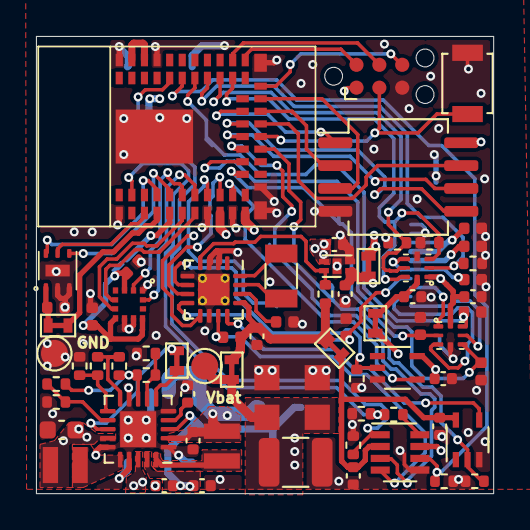
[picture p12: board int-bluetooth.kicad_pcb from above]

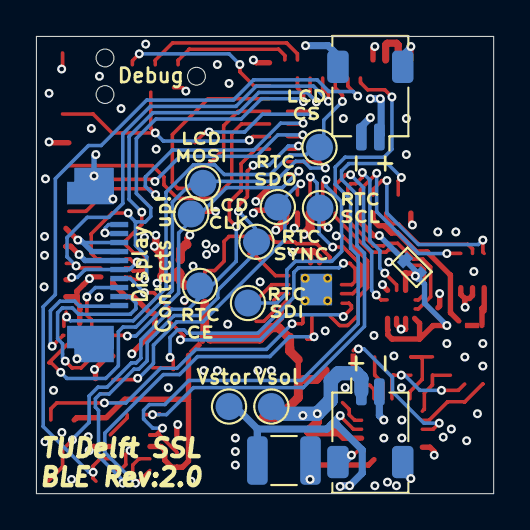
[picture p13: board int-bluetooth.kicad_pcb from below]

Board: 4 copper layers, 25.4 x 25.4 mm, 85 parts (15 on the bottom side), 70 nets.

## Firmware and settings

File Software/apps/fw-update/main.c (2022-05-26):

/*************************************************************************************************/
/*!
 *  \file
 *
 *  \brief  Custom service server.
 *
 *  Copyright (c) 2012-2018 Arm Ltd.
 *
 *  Copyright (c) 2019 Packetcraft, Inc.
 *
 *  Copyright (c) 2022 Delft University of Technology.
 *
 *  Licensed under the Apache License, Version 2.0 (the "License");
 *  you may not use this file except in compliance with the License.
 *  You may obtain a copy of the License at
 *
 *      http://www.apache.org/licenses/LICENSE-2.0
 *
 *  Unless required by applicable law or agreed to in writing, software
 *  distributed under the License is distributed on an "AS IS" BASIS,
 *  WITHOUT WARRANTIES OR CONDITIONS OF ANY KIND, either express or implied.
 *  See the License for the specific language governing permissions and
 *  limitations under the License.
 */
/*************************************************************************************************/

#include "wsf_types.h"
#include "wsf_trace.h"
#include "wsf_bufio.h"
#include "wsf_msg.h"
#include "wsf_assert.h"
#include "wsf_buf.h"
#include "wsf_heap.h"
#include "wsf_cs.h"
#include "wsf_timer.h"
#include "wsf_os.h"

#include "sec_api.h"
#include "hci_handler.h"
#include "dm_handler.h"
#include "l2c_handler.h"
#include "att_handler.h"
#include "smp_handler.h"
#include "l2c_api.h"
#include "att_api.h"
#include "smp_api.h"
#include "app_api.h"
#include "hci_core.h"
#include "sec_api.h"
#include "app_terminal.h"

#if defined(HCI_TR_EXACTLE) && (HCI_TR_EXACTLE == 1)
#include "ll_init_api.h"
#endif

#include "pal_bb.h"
#include "pal_cfg.h"

#include "template_api.h"
#include "app_ui.h"

#include "fram.h"
#ifdef CHECKPOINT
  #include "checkpoint.h"
  #ifdef CHECKPOINT_TIMING
    #include "platform.h"
    #include "ext-rtc.h"
    #include "bf_sync.h"
  #endif
#endif

#ifdef TRACE_TIMING
  #include "nrf.h"
  #include "nrf_gpio.h"
  #include "nrfx_gpiote.h"
  #include "pal_led.h"
#endif

#include <string.h>

/**************************************************************************************************
  Macros
**************************************************************************************************/

/*! \brief UART TX buffer size */
#define PLATFORM_UART_TERMINAL_BUFFER_SIZE      2048U

/**************************************************************************************************
  Global Variables
**************************************************************************************************/

/*! \brief  Pool runtime configuration. */
static wsfBufPoolDesc_t mainPoolDesc[] =
{
  { 16,              8 },
  { 32,              4 },
  { 192,             8 },
  { 256,             8 }
};

#if defined(HCI_TR_EXACTLE) && (HCI_TR_EXACTLE == 1)
  static LlRtCfg_t mainLlRtCfg;
#endif

/**************************************************************************************************
  Functions
**************************************************************************************************/

/*! \brief  Stack initialization for app. */
extern void StackInitTemplate(void);

/*************************************************************************************************/
/*!
 *  \brief  Initialize WSF.
 *
 *  \return None.
 */
/*************************************************************************************************/
static void mainWsfInit(void)
{
#if defined(HCI_TR_EXACTLE) && (HCI_TR_EXACTLE == 1)
  /* +12 for message headroom, + 2 event header, +255 maximum parameter length. */
  const uint16_t maxRptBufSize = 12 + 2 + 255;

  /* +12 for message headroom, +4 for header. */
  const uint16_t aclBufSize = 12 + mainLlRtCfg.maxAclLen + 4 + BB_DATA_PDU_TAILROOM;

  /* Adjust buffer allocation based on platform configuration. */
  mainPoolDesc[2].len = maxRptBufSize;
  mainPoolDesc[2].num = mainLlRtCfg.maxAdvReports;
  mainPoolDesc[3].len = aclBufSize;
  mainPoolDesc[3].num = mainLlRtCfg.numTxBufs + mainLlRtCfg.numRxBufs;
#endif

  const uint8_t numPools = sizeof(mainPoolDesc) / sizeof(mainPoolDesc[0]);

  uint16_t memUsed;
  memUsed = WsfBufInit(numPools, mainPoolDesc);
  WsfHeapAlloc(memUsed);
  WsfOsInit();
  WsfTimerInit();
#if (WSF_TOKEN_ENABLED == TRUE) || (WSF_TRACE_ENABLED == TRUE)
  WsfTraceRegisterHandler(WsfBufIoWrite);
  WsfTraceEnable(TRUE);
#endif
}

#ifdef TRACE_TIMING
void SWI0_EGU0_IRQHandler(void) {
  if (NRF_EGU0->EVENTS_TRIGGERED[0]) {
    /* Clear event register */
    NRF_EGU0->EVENTS_TRIGGERED[0] = 0;
    nrf_gpio_pin_set(DEBUG_INFO_BLE);
  } else { 
    /* Clear event register */
    NRF_EGU0->EVENTS_TRIGGERED[1] = 0;
    NRF_EGU0->EVENTS_TRIGGERED[2] = 0;
    nrf_gpio_pin_clear(DEBUG_INFO_BLE);
  }
}

void TraceTimingConfig() {
  NVIC_SetPriority(SWI0_EGU0_IRQn, 2);
  NVIC_EnableIRQ(SWI0_EGU0_IRQn);

  NRF_EGU0->INTENSET = 1 << 0;
  NRF_PPI->CH[1].EEP = (uint32_t) &NRF_RADIO->EVENTS_READY;  /* configure event */
  NRF_PPI->CH[1].TEP = (uint32_t) &NRF_EGU0->TASKS_TRIGGER[0];    /* configure task */
  NRF_PPI->CHENSET = 1 << 1;                            /* enable channel */

  NRF_EGU0->INTENSET = 1 << 1;
  NRF_PPI->CH[2].EEP = (uint32_t) &NRF_RADIO->EVENTS_END;  /* configure event */
  NRF_PPI->CH[2].TEP = (uint32_t) &NRF_EGU0->TASKS_TRIGGER[1];    /* configure task */
  NRF_PPI->CHENSET = 1 << 2;                            /* enable channel */

  NRF_EGU0->INTENSET = 1 << 2;
  NRF_PPI->CH[3].EEP = (uint32_t) &NRF_RADIO->EVENTS_DISABLED;  /* configure event */
  NRF_PPI->CH[3].TEP = (uint32_t) &NRF_EGU0->TASKS_TRIGGER[2];    /* configure task */
  NRF_PPI->CHENSET = 1 << 3;                            /* enable channel */
}
#endif

int main(void) {
  framConfig();
#ifdef CHECKPOINT_TIMING
 extRtcConfig();
 bfSyncConfig();
#endif
 framConfig();
#ifdef TRACE_TIMING
 TraceTimingConfig();
 nrf_gpio_pin_set(DEBUG_INFO_CKPT);
#endif
#ifdef CHECKPOINT
 checkpoint_init();
#endif

#if defined(HCI_TR_EXACTLE) && (HCI_TR_EXACTLE == 1)
 /* Configurations must be persistent. */
 static BbRtCfg_t mainBbRtCfg;

 PalBbLoadCfg((PalBbCfg_t *)&mainBbRtCfg);
 LlGetDefaultRunTimeCfg(&mainLlRtCfg);
#if (BT_VER >= LL_VER_BT_CORE_SPEC_5_0)
 /* Set 5.0 requirements. */
 mainLlRtCfg.btVer = LL_VER_BT_CORE_SPEC_5_0;
#endif
 PalCfgLoadData(PAL_CFG_ID_LL_PARAM, &mainLlRtCfg.maxAdvSets, sizeof(LlRtCfg_t) - 9);
#if (BT_VER >= LL_VER_BT_CORE_SPEC_5_0)
 PalCfgLoadData(PAL_CFG_ID_BLE_PHY, &mainLlRtCfg.phy2mSup, 4);
#endif
#endif

 uint32_t memUsed;
// memUsed = WsfBufIoUartInit(WsfHeapGetFreeStartAddress(), PLATFORM_UART_TERMINAL_BUFFER_SIZE);
// WsfHeapAlloc(memUsed);

 mainWsfInit();
 AppTerminalInit();

#if defined(HCI_TR_EXACTLE) && (HCI_TR_EXACTLE == 1)
 LlInitRtCfg_t llCfg =
 {
   .pBbRtCfg     = &mainBbRtCfg,
   .wlSizeCfg    = 4,
   .rlSizeCfg    = 4,
   .plSizeCfg    = 4,
   .pLlRtCfg     = &mainLlRtCfg,
   .pFreeMem     = WsfHeapGetFreeStartAddress(),
   .freeMemAvail = WsfHeapCountAvailable()
 };

 memUsed = LlInit(&llCfg);
 WsfHeapAlloc(memUsed);

 bdAddr_t bdAddr;
 PalCfgLoadData(PAL_CFG_ID_BD_ADDR, bdAddr, sizeof(bdAddr_t));
 LlSetBdAddr((uint8_t *)&bdAddr);
 LlMathSetSeed((uint32_t *)&bdAddr);
#endif

 StackInitTemplate();
 TemplateStart();

 WsfOsEnterMainLoop();

 /* Does not return. */
 return 0;
}

/**
 *@}
 **/

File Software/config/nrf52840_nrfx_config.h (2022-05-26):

/*************************************************************************************************/
/*!
 *  \file
 *
 *  \brief      NRFX configuration.
 *
 *  Copyright (c) 2019-2020 Packetcraft, Inc. 
 * 
 *  Copyright (c) 2022 Delft University of Technology.
 *  
 *  Licensed under the Apache License, Version 2.0 (the "License");
 *  you may not use this file except in compliance with the License.
 *  You may obtain a copy of the License at
 *  
 *      http://www.apache.org/licenses/LICENSE-2.0
 *  
 *  Unless required by applicable law or agreed to in writing, software
 *  distributed under the License is distributed on an "AS IS" BASIS,
 *  WITHOUT WARRANTIES OR CONDITIONS OF ANY KIND, either express or implied.
 *  See the License for the specific language governing permissions and
 *  limitations under the License.
 */
/*************************************************************************************************/

#ifndef NRFX_CONFIG_H
#define NRFX_CONFIG_H

#define NRFX_CLOCK_ENABLED 1
#define NRFX_CLOCK_CONFIG_LF_SRC 1
#define NRFX_CLOCK_CONFIG_LF_CAL_ENABLED 0
#define NRFX_CLOCK_CONFIG_IRQ_PRIORITY 7

#define NRFX_CLOCK_CONFIG_LOG_ENABLED 0
#define NRFX_CLOCK_CONFIG_LOG_LEVEL 3
#define NRFX_CLOCK_CONFIG_INFO_COLOR 0
#define NRFX_CLOCK_CONFIG_DEBUG_COLOR 0

#define NRFX_COMP_ENABLED 0
#define NRFX_COMP_CONFIG_REF 1
#define NRFX_COMP_CONFIG_MAIN_MODE 0
#define NRFX_COMP_CONFIG_SPEED_MODE 2
#define NRFX_COMP_CONFIG_HYST 0
#define NRFX_COMP_CONFIG_ISOURCE 0
#define NRFX_COMP_CONFIG_INPUT 0
#define NRFX_COMP_CONFIG_IRQ_PRIORITY 7

#define NRFX_COMP_CONFIG_LOG_ENABLED 0
#define NRFX_COMP_CONFIG_LOG_LEVEL 3
#define NRFX_COMP_CONFIG_INFO_COLOR 0
#define NRFX_COMP_CONFIG_DEBUG_COLOR 0

#define NRFX_GPIOTE_ENABLED 1
#define NRFX_GPIOTE_CONFIG_NUM_OF_LOW_POWER_EVENTS 8
#define NRFX_GPIOTE_CONFIG_IRQ_PRIORITY 7

#define NRFX_GPIOTE_CONFIG_LOG_ENABLED 0
#define NRFX_GPIOTE_CONFIG_LOG_LEVEL 3
#define NRFX_GPIOTE_CONFIG_INFO_COLOR 0
#define NRFX_GPIOTE_CONFIG_DEBUG_COLOR 0

#define NRFX_I2S_ENABLED 0

#if AUDIO_CAPE
#define NRFX_I2S_CONFIG_SCK_PIN NRF_GPIO_PIN_MAP(1,11)
#define NRFX_I2S_CONFIG_LRCK_PIN NRF_GPIO_PIN_MAP(1,12)
#define NRFX_I2S_CONFIG_MCK_PIN NRF_GPIO_PIN_MAP(1,10)
#define NRFX_I2S_CONFIG_SDOUT_PIN NRF_GPIO_PIN_MAP(1,14)
#define NRFX_I2S_CONFIG_SDIN_PIN NRF_GPIO_PIN_MAP(1,13)
#elif defined(BOARD_NRF6832)
#define NRFX_I2S_CONFIG_SCK_PIN 19
#define NRFX_I2S_CONFIG_LRCK_PIN 20
#define NRFX_I2S_CONFIG_MCK_PIN NRFX_I2S_PIN_NOT_USED
#define NRFX_I2S_CONFIG_SDOUT_PIN 22
#define NRFX_I2S_CONFIG_SDIN_PIN 23
#else
#define NRFX_I2S_CONFIG_SCK_PIN 31
#define NRFX_I2S_CONFIG_LRCK_PIN 30
#define NRFX_I2S_CONFIG_MCK_PIN 255
#define NRFX_I2S_CONFIG_SDOUT_PIN 29
#define NRFX_I2S_CONFIG_SDIN_PIN 28
#endif

#define NRFX_I2S_CONFIG_MASTER 0
#define NRFX_I2S_CONFIG_FORMAT 0
#define NRFX_I2S_CONFIG_ALIGN 0
#define NRFX_I2S_CONFIG_SWIDTH 1
#define NRFX_I2S_CONFIG_CHANNELS 1
#define NRFX_I2S_CONFIG_MCK_SETUP 536870912
#define NRFX_I2S_CONFIG_RATIO 5
#define NRFX_I2S_CONFIG_IRQ_PRIORITY 7

#define NRFX_I2S_CONFIG_LOG_ENABLED 0
#define NRFX_I2S_CONFIG_LOG_LEVEL 3
#define NRFX_I2S_CONFIG_INFO_COLOR 0
#define NRFX_I2S_CONFIG_DEBUG_COLOR 0

#define NRFX_LPCOMP_ENABLED 0
#define NRFX_LPCOMP_CONFIG_REFERENCE 3
#define NRFX_LPCOMP_CONFIG_DETECTION 2
#define NRFX_LPCOMP_CONFIG_INPUT 0
#define NRFX_LPCOMP_CONFIG_HYST 0
#define NRFX_LPCOMP_CONFIG_IRQ_PRIORITY 7

#define NRFX_LPCOMP_CONFIG_LOG_ENABLED 0
#define NRFX_LPCOMP_CONFIG_LOG_LEVEL 3
#define NRFX_LPCOMP_CONFIG_INFO_COLOR 0
#define NRFX_LPCOMP_CONFIG_DEBUG_COLOR 0

#define NRFX_NFCT_ENABLED 0
#define NRFX_NFCT_CONFIG_IRQ_PRIORITY 7

#define NRFX_NFCT_CONFIG_LOG_ENABLED 0
#define NRFX_NFCT_CONFIG_LOG_LEVEL 3
#define NRFX_NFCT_CONFIG_INFO_COLOR 0
#define NRFX_NFCT_CONFIG_DEBUG_COLOR 0

#define NRFX_NVMC_ENABLED 0

#define NRFX_PDM_ENABLED 0
#define NRFX_PDM_CONFIG_MODE 1
#define NRFX_PDM_CONFIG_EDGE 0
#define NRFX_PDM_CONFIG_CLOCK_FREQ 138412032
#define NRFX_PDM_CONFIG_IRQ_PRIORITY 7

#define NRFX_PDM_CONFIG_LOG_ENABLED 0
#define NRFX_PDM_CONFIG_LOG_LEVEL 3
#define NRFX_PDM_CONFIG_INFO_COLOR 0
#define NRFX_PDM_CONFIG_DEBUG_COLOR 0

#define NRFX_POWER_ENABLED 1
#define NRFX_POWER_CONFIG_IRQ_PRIORITY 7
#define NRFX_POWER_CONFIG_DEFAULT_DCDCEN 0
#define NRFX_POWER_CONFIG_DEFAULT_DCDCENHV 0

#define NRFX_PPI_ENABLED 1

#define NRFX_PPI_CONFIG_LOG_ENABLED 0
#define NRFX_PPI_CONFIG_LOG_LEVEL 3
#define NRFX_PPI_CONFIG_INFO_COLOR 0
#define NRFX_PPI_CONFIG_DEBUG_COLOR 0

#define NRFX_PRS_ENABLED 0
#define NRFX_PRS_BOX_0_ENABLED 0
#define NRFX_PRS_BOX_1_ENABLED 0
#define NRFX_PRS_BOX_2_ENABLED 0
#define NRFX_PRS_BOX_3_ENABLED 0
#define NRFX_PRS_BOX_4_ENABLED 0

#define NRFX_PRS_CONFIG_LOG_ENABLED 0
#define NRFX_PRS_CONFIG_LOG_LEVEL 3
#define NRFX_PRS_CONFIG_INFO_COLOR 0
#define NRFX_PRS_CONFIG_DEBUG_COLOR 0
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

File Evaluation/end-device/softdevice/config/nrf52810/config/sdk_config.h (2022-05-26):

/**
 * Copyright (c) 2017 - 2020, Nordic Semiconductor ASA
 *
 * All rights reserved.
 *
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
 * 3. Neither the name of Nordic Semiconductor ASA nor the names of its
 *    contributors may be used to endorse or promote products derived from this
 *    software without specific prior written permission.
 *
 * 4. This software, with or without modification, must only be used with a
 *    Nordic Semiconductor ASA integrated circuit.
 *
 * 5. Any software provided in binary form under this license must not be reverse
 *    engineered, decompiled, modified and/or disassembled.
 *
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
 */



#ifndef SDK_CONFIG_H
#define SDK_CONFIG_H
// <<< Use Configuration Wizard in Context Menu >>>\n
#ifdef USE_APP_CONFIG
#include "app_config.h"
#endif
// <h> nRF_BLE 

//==========================================================
// <q> BLE_ADVERTISING_ENABLED  - ble_advertising - Advertising module
 

#ifndef BLE_ADVERTISING_ENABLED
#define BLE_ADVERTISING_ENABLED 0
#endif

// <q> BLE_DTM_ENABLED  - ble_dtm - Module for testing RF/PHY using DTM commands
 

#ifndef BLE_DTM_ENABLED
#define BLE_DTM_ENABLED 0
#endif

// <q> BLE_RACP_ENABLED  - ble_racp - Record Access Control Point library
 

#ifndef BLE_RACP_ENABLED
#define BLE_RACP_ENABLED 0
#endif

// <e> NRF_BLE_QWR_ENABLED - nrf_ble_qwr - Queued writes support module (prepare/execute write)
//==========================================================
#ifndef NRF_BLE_QWR_ENABLED
#define NRF_BLE_QWR_ENABLED 0
#endif
// <o> NRF_BLE_QWR_MAX_ATTR - Maximum number of attribute handles that can be registered. This number must be adjusted according to the number of attributes for which Queued Writes will be enabled. If it is zero, the module will reject all Queued Write requests. 
#ifndef NRF_BLE_QWR_MAX_ATTR
#define NRF_BLE_QWR_MAX_ATTR 0
#endif

// </e>

// <e> PEER_MANAGER_ENABLED - peer_manager - Peer Manager
//==========================================================
#ifndef PEER_MANAGER_ENABLED
#define PEER_MANAGER_ENABLED 0
#endif
// <o> PM_MAX_REGISTRANTS - Number of event handlers that can be registered. 
#ifndef PM_MAX_REGISTRANTS
#define PM_MAX_REGISTRANTS 3
#endif

// <o> PM_FLASH_BUFFERS - Number of internal buffers for flash operations. 
// <i> Decrease this value to lower RAM usage.

#ifndef PM_FLASH_BUFFERS
#define PM_FLASH_BUFFERS 4
#endif

// <q> PM_CENTRAL_ENABLED  - Enable/disable central-specific Peer Manager functionality.
 

// <i> Enable/disable central-specific Peer Manager functionality.

#ifndef PM_CENTRAL_ENABLED
#define PM_CENTRAL_ENABLED 1
#endif

// <q> PM_SERVICE_CHANGED_ENABLED  - Enable/disable the service changed management for GATT server in Peer Manager.
 

// <i> If not using a GATT server, or using a server wihout a service changed characteristic,
// <i> disable this to save code space.

#ifndef PM_SERVICE_CHANGED_ENABLED
#define PM_SERVICE_CHANGED_ENABLED 1
#endif

// <q> PM_PEER_RANKS_ENABLED  - Enable/disable the peer rank management in Peer Manager.
 

// <i> Set this to false to save code space if not using the peer rank API.

#ifndef PM_PEER_RANKS_ENABLED
#define PM_PEER_RANKS_ENABLED 1
#endif

// <q> PM_LESC_ENABLED  - Enable/disable LESC support in Peer Manager.
 

// <i> If set to true, you need to call nrf_ble_lesc_request_handler() in the main loop to respond to LESC-related BLE events. If LESC support is not required, set this to false to save code space.

#ifndef PM_LESC_ENABLED
#define PM_LESC_ENABLED 0
#endif

// <e> PM_RA_PROTECTION_ENABLED - Enable/disable protection against repeated pairing attempts in Peer Manager.
//==========================================================
#ifndef PM_RA_PROTECTION_ENABLED
#define PM_RA_PROTECTION_ENABLED 0
#endif
// <o> PM_RA_PROTECTION_TRACKED_PEERS_NUM - Maximum number of peers whose authorization status can be tracked. 
#ifndef PM_RA_PROTECTION_TRACKED_PEERS_NUM
#define PM_RA_PROTECTION_TRACKED_PEERS_NUM 8
#endif

// <o> PM_RA_PROTECTION_MIN_WAIT_INTERVAL - Minimum waiting interval (in ms) before a new pairing attempt can be initiated. 
#ifndef PM_RA_PROTECTION_MIN_WAIT_INTERVAL
#define PM_RA_PROTECTION_MIN_WAIT_INTERVAL 4000
#endif

// <o> PM_RA_PROTECTION_MAX_WAIT_INTERVAL - Maximum waiting interval (in ms) before a new pairing attempt can be initiated. 
#ifndef PM_RA_PROTECTION_MAX_WAIT_INTERVAL
#define PM_RA_PROTECTION_MAX_WAIT_INTERVAL 64000
#endif

// <o> PM_RA_PROTECTION_REWARD_PERIOD - Reward period (in ms). 
// <i> The waiting interval is gradually decreased when no new failed pairing attempts are made during reward period.

#ifndef PM_RA_PROTECTION_REWARD_PERIOD
#define PM_RA_PROTECTION_REWARD_PERIOD 10000
#endif

// </e>

// <o> PM_HANDLER_SEC_DELAY_MS - Delay before starting security. 
// <i>  This might be necessary for interoperability reasons, especially as peripheral.

#ifndef PM_HANDLER_SEC_DELAY_MS
#define PM_HANDLER_SEC_DELAY_MS 0
#endif

// </e>

// </h> 
//==========================================================

// <h> nRF_BLE_Services
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

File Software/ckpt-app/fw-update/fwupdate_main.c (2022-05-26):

/*************************************************************************************************/
/*!
 *  Copyright (c) 2022 Delft University of Technology.
 *  Jasper de Winkel, Haozhe Tang and Przemyslaw Pawelczak
 *
 *  Licensed under the Apache License, Version 2.0 (the "License");
 *  you may not use this file except in compliance with the License.
 *  You may obtain a copy of the License at
 *
 *      http://www.apache.org/licenses/LICENSE-2.0
 *
 *  Unless required by applicable law or agreed to in writing, software
 *  distributed under the License is distributed on an "AS IS" BASIS,
 *  WITHOUT WARRANTIES OR CONDITIONS OF ANY KIND, either express or implied.
 *  See the License for the specific language governing permissions and
 *  limitations under the License.
 */
/*************************************************************************************************/

#include <string.h>

#include "wsf_types.h"
#include "wsf_trace.h"
#include "wsf_bufio.h"
#include "wsf_msg.h"
#include "wsf_assert.h"
#include "wsf_buf.h"
#include "wsf_heap.h"
#include "wsf_cs.h"
#include "wsf_timer.h"
#include "wsf_app_timer.h"
#include "wsf_os.h"

#include "cus_api.h"
#include "fwupdate_api.h"

#include "platform.h"
#include "nrf.h"
#include "nrf_delay.h"
#include "nrf_gpio.h"
#include "nrfx_gpiote.h"
#include "pal_led.h"
#include "fram.h"

#ifdef CHECKPOINT
#include "checkpoint.h"
#include "checkpoint_content.h"
#endif

extern const uint32_t  _sfirmware_0; // start firmware 0 in fram
extern const uint32_t  _efirmware_0; // end of firmware 0 in fram
extern const uint32_t  _sfirmware_1;
extern const uint32_t  _efirmware_1;
extern const uint32_t  _sfirmware_rom; // start firmware in flash 4k aligned
extern const uint32_t  _efirmware_rom; //

// defines the linker script to include the flash section, comment out/remove for non firmware update applications
__attribute__((section(".allocate_firmware_flags"))) char _allocate_firmware_ld; 


// __attribute__((section(".firmware_rom"))) __attribute__((target("thumb"))) void firmware_a() {
//   for (volatile uint8_t j = 32; j > 0; j--);
// }
__attribute__((section(".firmware_rom"))) static const uint8_t firmware_rom[] = {
    0x82, 0xB0, 0x20, 0x23, 0x8D, 0xF8, 0x07, 0x30,
    0x06, 0xE0, 0x9D, 0xF8, 0x07, 0x30, 0xDB, 0xB2,
    0x01, 0x3B, 0xDB, 0xB2, 0x8D, 0xF8, 0x07, 0x30,
    0x9D, 0xF8, 0x07, 0x30, 0xDB, 0xB2, 0x00, 0x2B,
    0xF3, 0xD1, 0x00, 0xBF, 0x00, 0xBF, 0x02, 0xB0,
    0x70, 0x47, 0xff, 0xff, 0xff, 0xff, 0xff, 0xff,
  0xFF, 0xFF, 0xFF, 0xFF, 0xFF, 0xFF, 0xFF, 0xFF,
  0xFF, 0xFF, 0xFF, 0xFF, 0xFF, 0xFF, 0xFF, 0xFF,
  0xFF, 0xFF, 0xFF, 0xFF, 0xFF, 0xFF, 0xFF, 0xFF,
  0xFF, 0xFF, 0xFF, 0xFF, 0xFF, 0xFF, 0xFF, 0xFF,
  0xFF, 0xFF, 0xFF, 0xFF, 0xFF, 0xFF, 0xFF, 0xFF,
  0xFF, 0xFF, 0xFF, 0xFF, 0xFF, 0xFF, 0xFF, 0xFF
};

// __attribute__((section(".firmware_rom"))) __attribute__((target("thumb"))) void firmware_b() {
//   const uint32_t pos = 1UL << 16;
//   uint32_t pins_state;

//   for (volatile uint8_t j = 32; j > 0; j--);

//   pins_state = NRF_P0->OUT;
//   NRF_P0->OUTSET = (~pins_state & pos);
//   NRF_P0->OUTCLR = (pins_state & pos);
// }
// __attribute__((section(".firmware_rom"))) static const uint8_t firmware_rom[] = {
//     0x84, 0xB0, 0x4F, 0xF4, 0x80, 0x33, 0x03, 0x93,
//     0x20, 0x23, 0x8D, 0xF8, 0x07, 0x30, 0x06, 0xE0,
//     0x9D, 0xF8, 0x07, 0x30, 0xDB, 0xB2, 0x01, 0x3B,
//     0xDB, 0xB2, 0x8D, 0xF8, 0x07, 0x30, 0x9D, 0xF8,
//     0x07, 0x30, 0xDB, 0xB2, 0x00, 0x2B, 0xF3, 0xD1,
//     0x4F, 0xF0, 0xA0, 0x43, 0xD3, 0xF8, 0x04, 0x35,
//     0x02, 0x93, 0x02, 0x9B, 0xDA, 0x43, 0x4F, 0xF0,
//     0xA0, 0x41, 0x03, 0x9B, 0x13, 0x40, 0xC1, 0xF8,
//     0x08, 0x35, 0x4F, 0xF0, 0xA0, 0x41, 0x02, 0x9A,
//     0x03, 0x9B, 0x13, 0x40, 0xC1, 0xF8, 0x0C, 0x35,
//     0x00, 0xBF, 0x04, 0xB0, 0x70, 0x47, 0xff, 0xff,
//   0xFF, 0xFF, 0xFF, 0xFF, 0xFF, 0xFF, 0xFF, 0xFF
// };

firmware_ptr_t firmware_ptr;

static struct {
  fwUpdateCfg_t cfg;                  /*! \brief configurable parameters */
  uint8_t firmware_lclock;
  uint8_t firmware_len;
} fwUpdateCb;

static void startup_populate_firmware(void){
    // firmware_a();  // keep it not optimized out
    // firmware_b();  // keep it not optimized out

    char *firmware_fram = (char *)&_sfirmware_0;
    // char *firmware_init = (char *)&_sfirmware_rom;
    char *firmware_init = (char *)firmware_rom;  // keep firmware_rom not optimized out

    uint8_t tempBuffer[sizeof(firmware_rom)]; // as long as the firmware is small this should be fine.
    memcpy(tempBuffer,firmware_init, sizeof(firmware_rom)); // workaroud since QSPI can only write from SRAM...
    framWrite(firmware_fram, tempBuffer, sizeof(firmware_rom));
}

static void FwUpdateSetFirmwarePtr() {
  uint32_t firmware_ptr_val;
  if (fwUpdateCb.firmware_lclock % 2 == 0) {
    firmware_ptr_val = (uint32_t)&_sfirmware_0;
  } else {
    firmware_ptr_val = (uint32_t)&_sfirmware_1;
  }
  // firmware pointer will be compiled to a `BLX` instruction
  // setting bit 0 to force the thumb state
  firmware_ptr_val |= 1UL;
  firmware_ptr = (firmware_ptr_t)firmware_ptr_val;
  fwUpdateCb.firmware_lclock++;
}

static void FwUpdateFinish() {
  FwUpdateSetFirmwarePtr();
  custom_control_point = 0;
  customSetupToSendCp();
  customSendCpNtf();
  /* restart timer */
#ifdef CHECKPOINT
  WsfAppTimerStartMs(&fwExeTimer, fwUpdateCb.cfg.period);
#else
  WsfTimerStartMs(&fwExeTimer, fwUpdateCb.cfg.period);
#endif
}

static void fwExeTimerExp(wsfMsgHdr_t *pMsg) {
  if (custom_control_point == 0x00) {
    /* restart timer */
#ifdef CHECKPOINT
  WsfAppTimerStartMs(&fwExeTimer, fwUpdateCb.cfg.period);
#else
  WsfTimerStartMs(&fwExeTimer, fwUpdateCb.cfg.period);
#endif
    firmware_ptr();
  }
}

void FwUpdateInit(wsfHandlerId_t handlerId, fwUpdateCfg_t *pCfg) {
  fwExeTimer.handlerId = handlerId;
  fwUpdateCb.cfg = *pCfg;
  fwUpdateCb.firmware_lclock = 0;
  startup_populate_firmware();
  FwUpdateSetFirmwarePtr();
}

void FwUpdateStart(uint8_t timerEvt) {
  /* initialize control block */
  fwExeTimer.msg.event = timerEvt;

  /* start timer */
#ifdef CHECKPOINT
  WsfAppTimerStartMs(&fwExeTimer, fwUpdateCb.cfg.period);
#else
  WsfTimerStartMs(&fwExeTimer, fwUpdateCb.cfg.period);
#endif
}

void FwUpdateStop(){
#ifdef CHECKPOINT
  WsfAppTimerStop(&fwExeTimer);
#else
  WsfTimerStop(&fwExeTimer);
#endif
}

void FwUpdateProcMsg(wsfMsgHdr_t *pMsg){
  nrf_gpio_pin_set(DEBUG_INFO_APP);
#ifdef CHECKPOINT
  if (!app_restored) {
    nrf_gpio_pin_set(DEBUG_INFO_APP_CKPT);
    restore_application();
    app_restored = true;
    nrf_gpio_pin_clear(DEBUG_INFO_APP_CKPT);
  }
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
